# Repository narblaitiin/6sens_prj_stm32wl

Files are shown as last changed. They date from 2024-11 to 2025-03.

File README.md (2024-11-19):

# 6Sens: inSitu Seismic System for Slope Stability Sensing

## Desciption
The goal is to develop a warning system on the analysis of the evolution of the micro-seismic activity generated before the instability is triggered. The method uses a multitude of low-cost seismic sensors deployed in-situ in a network over the possibly unstable zone. The goal is to characterize the temporal evolution of seismic signals detected simultaneously by several sensors (i .e., co-detection). This method uses to its advantage the heterogeneity of the materials and the attenuation of the waves during their propagation in the material.

The design of these sensors is subject to certain technical constraints essential to good
operation of the project:

    - Be autonomous in energy, over a period of several months (so as not to have to return to site, often dangerous).
    - Be robust, reliable and adapted to extreme climatic conditions (cold, hot, humidity).
    - All sensors in the network must be synchronized precisely enough to perform the analysis (about 1/10 second).
    - Be able to communicate information in real time – or near – measurements to a gateway that will retransmit the data to a dedicated website.
    - Be produced at low cost (to install a large-scale network, and have the possibility of to install sensors in hazardous areas with the possibility of losing them).

## Hardware description
### Geophone sensor
The choice fell on omni geometric sensors from Geospace Technologies such Omni-X-LT or GS-ONE. Seismic geophone is a type of sensor that converts ground movement or a kind vibration into voltage, which could be acquired by an acquisition system. The deviation of this mesured voltage from the base line is called the geophone response and is analysed and for monitoring vibration generated by nature in our case.

The frequency response of the geophone is a kind of harmonic oscillator, which is deternined by corner frequency, around 15Hz for the chosen sensors and damping (typically 0.7 for our case).
Our application require the full wave to be sued and the three-component 3C geophones is used (Omni-X-LT or GS-ONE).
For more information, please to refer to : https://www.geospace.com/products/sensors/

### Amplification/Filtering board
The specifications inform us about the bandwidth of the filtering to be carried out: from 20Hz at 100Hz. So we have to build a band-pass filter having an amplification almost constant on this band and rejects frequencies outside this band. Moreover, the signal will have to be amplified in order to obtain a complete dynamic range between 0 and 3.3V without saturation. Below are listed the
parameters of the different filters that will make up the amplification and filtering card :

    - Filter 1 : active bandpass filter, gain : 33dB, low frequency : 7Hz, high frequency : 154Hz
    - Filter 2 : passive low-pass filter, no gain, cut frequency : 106Hz
    - Filter 3 : active low-pass filter, gain : 6dB, cut frequency : 234Hz

### CPU/Radio board for test
The choice fell on Cicerone MKR main board. Move-X Cicerone LoRa/GNSS Board is a high-performance, low-power, Arduino MKR-compatible development board based on the MAMWLE LoRa Module and the u-blox MAX-M10S GNSS Module. The Cicerone Board delivers best-in-class GNSS, long-range wireless connection, and high-performance MCU processing in a low-power solution for optimal battery life. The Cicerone Board allows users to build tracking applications worldwide with meter-level accuracy and to communicate long-range, low-power data via LoRaWAN. The integrated Li-Po charging circuit enables the Cicerone Board to manage battery charging through the USB port.

### CPU/Radio board for POC
The choice was made to manufacture our own PCB. It has three parts: the MAMWLE-01 radio chipset to transmit LoRaWAN packets (based on an STM32WLE5jx), a UWB chipset DW1000 to measure distance between two sensors and an analog part to supply radio chipset (solar panel or/and Li-Po battery). Connectors (Arduino MKR-compatible) have also been added to insert the seismic sensor amplification/filtering board.

## Firmware description
For this project, the use of Zephyr RTOS has been retained. To see what is Zephyr RTOS and how to install it on your computer, go to https://docs.zephyrproject.org/latest/develop/getting_started/index.html (it supports Linux OS, Windows OS and macOS).

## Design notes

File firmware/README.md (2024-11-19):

# Code for 6Sens Project : final code

## Overview
Here is the final code for the 6Sens (6Sens: inSitu Seismic System for Slope Stability Sensing) project. It makes it possible to measure seismic measurements and alert in the event of an alert. The data is stored in memory when an event appears and, when it stops, all samples are sent to the Lorawan networks servers then to a 5G network. All servers are implemeted in a Raspberry Pi3 model B and this gateway is powered by solar panel. In addition, the battery level and temperature/pressure/humidity of the node are taken every 30 minutes and sent to the network once a day.

## Building and Running
The following commands clean build folder, build and flash the sample:

**Command to use**

west build -t pristine

west build -p always -b stm32wl_dw1000_iot_board applications/stm32wle5_rtos_6sens

west flash --runner stm32cubeprogrammer

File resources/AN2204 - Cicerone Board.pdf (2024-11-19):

AN2204

# Application note

Hardware Specifications of Move-X Cicerone board

# Introduction

The purpose of this document is to guide users of Move-X Cicerone board in understanding and customizing the board’s hardware. To do this, the document provides electrical schematics that show how components are connected, and what kind of modifications can be done to adapt the board to different use cases.

For more resources, news, and links to official distributors for Move-X products, please visit Move-X website: https://www.move-x.it/.

For details on the Cicerone boards, documentation and buying options please visit the official website: https://www.move-x.it/cicerone-board/.

pag.

# Contents

Introduction

0
Contents

1
Electrical schematics

2
Connectors

2
USB

-UART interface chip

2
u

-blox MAX

-M10S module

3
Move

-X MAMWLE module

3
Auxiliary circuits

4
Hardware configuration

5
Document revision

6

# Electrical schematics

## Connectors

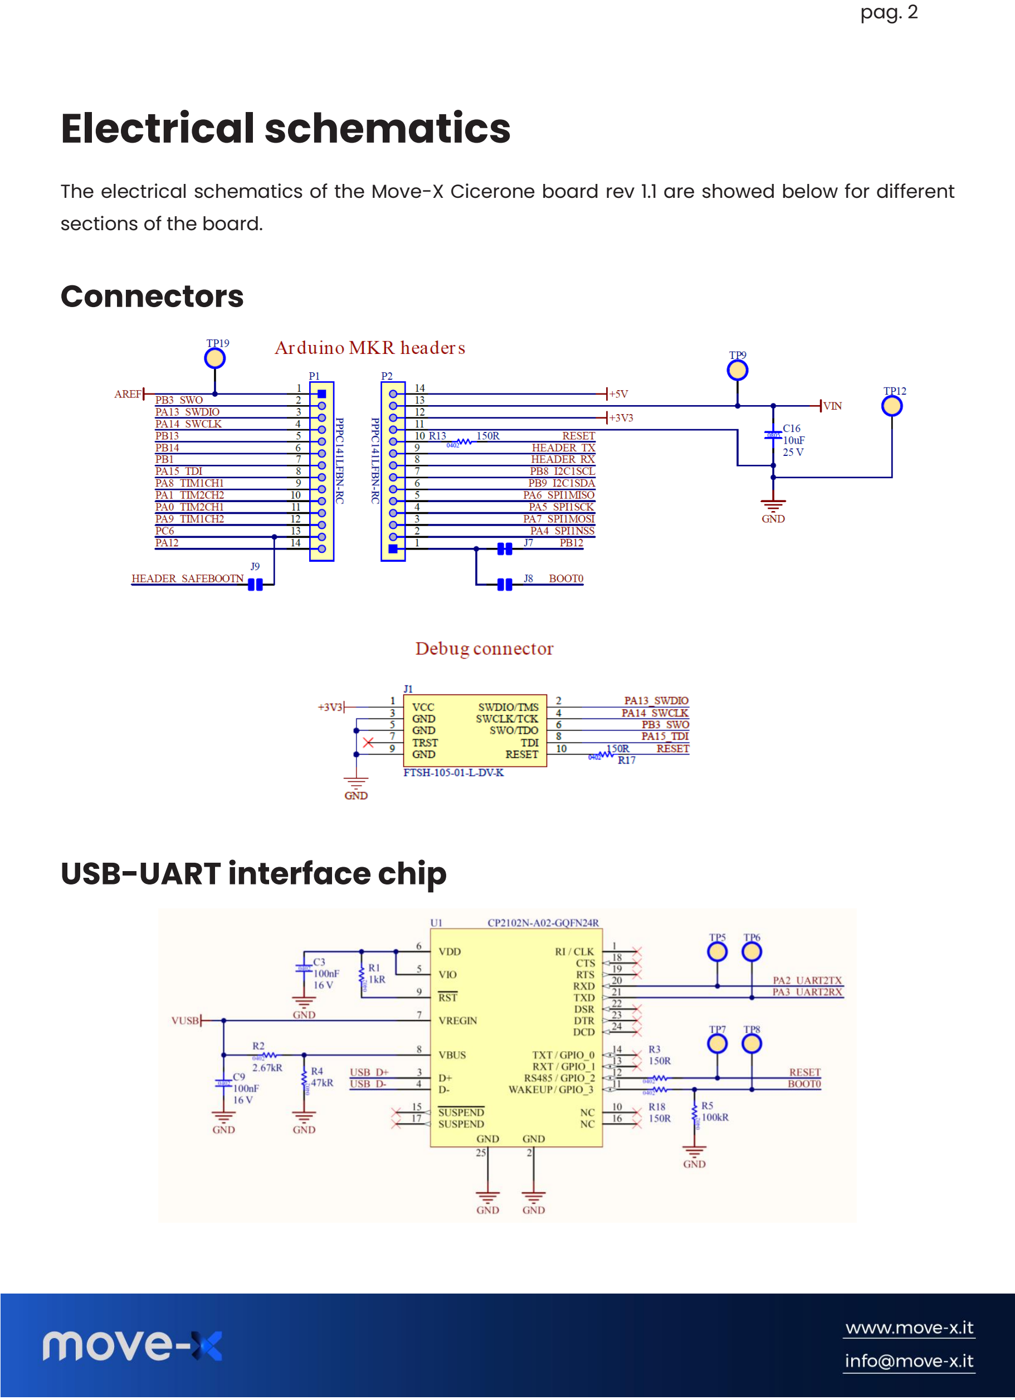
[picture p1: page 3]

The electrical schematics of the Move-X Cicerone board rev 1.1 are showed below for different sections of the board.

## USB-UART interface chip

## u-blox MAX-M10S module

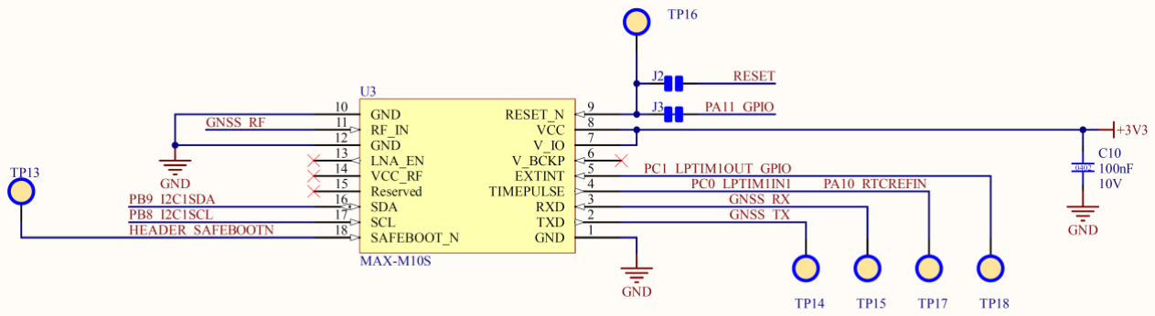
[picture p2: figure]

## Move-X MAMWLE module

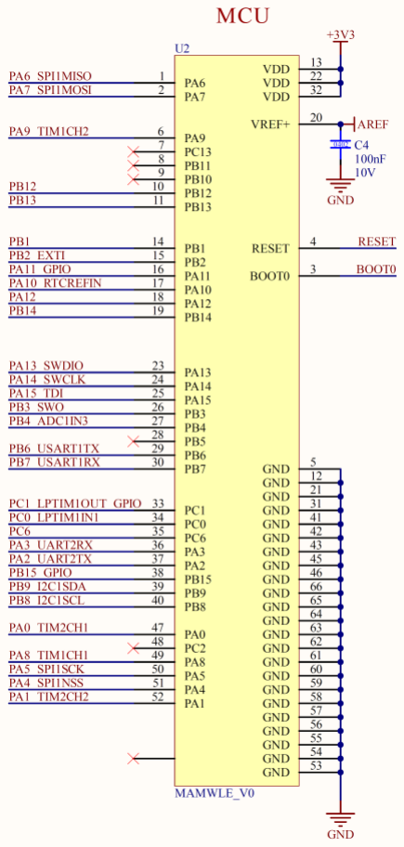
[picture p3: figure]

## Auxiliary circuits

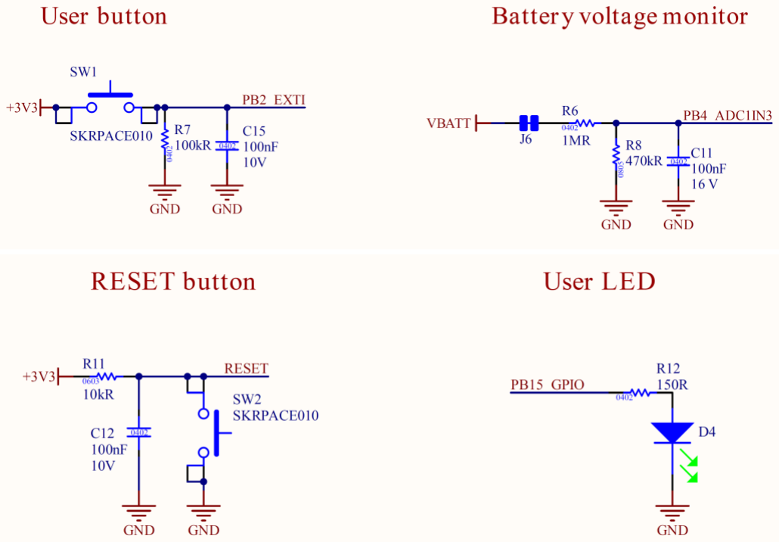
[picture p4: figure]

# Hardware configuration

The Cicerone board is equipped with some solder jumper on the bottom. These can be of two kinds as expressed in the schematics:
- Normally closed (NC): by default, the two terminals are shorted together, but can be separated by cutting the small track that connects the two pads.
- Normally open (NO): by default, the two terminals are not shorted together, but can be shorted by soldering them together.

The table below lists all the available solder jumpers with their respective function.

Designator | Default Type | Function description
J2 | NO | J2, J3 default state connects MAX-M10’s RESET_N pin to PA11. It is possible to close J2 and open J3 to connect MAX-M10’s RESET_N to the RESET net. J2 and J3 should not be both closed to avoid shorting RESET and PA11 nets.
J3 | NC
J6 | NC | Close by default for connecting the R6-R8 voltage divider to PB4, allowing battery voltage measurement using the ADC. Can be opened to disconnect this circuit from the battery.
J7 | NC | J7, J8 default state connects PB12 to the header pin #P2.1. It is possible to close J8 and open J7 to connect header pin #P2.1 to BOOT0 instead of PB12. J7 and J8 should not be both closed to avoid shorting BOOT0 and PB12 nets.
J8 | NO
J9 | NO | Open by default, can be closed to connect MAX-M10’s SAFEBOOT_N to header pin #P1.13 and PC6 net.
J10 | NC | Close by default, connects the battery charge IC to the battery. Can be open to disconnect the charging circuit from the battery. This allows to use non-rechargeable batteries.

## Document revision

Revision 1.0

- 23

/09/2022

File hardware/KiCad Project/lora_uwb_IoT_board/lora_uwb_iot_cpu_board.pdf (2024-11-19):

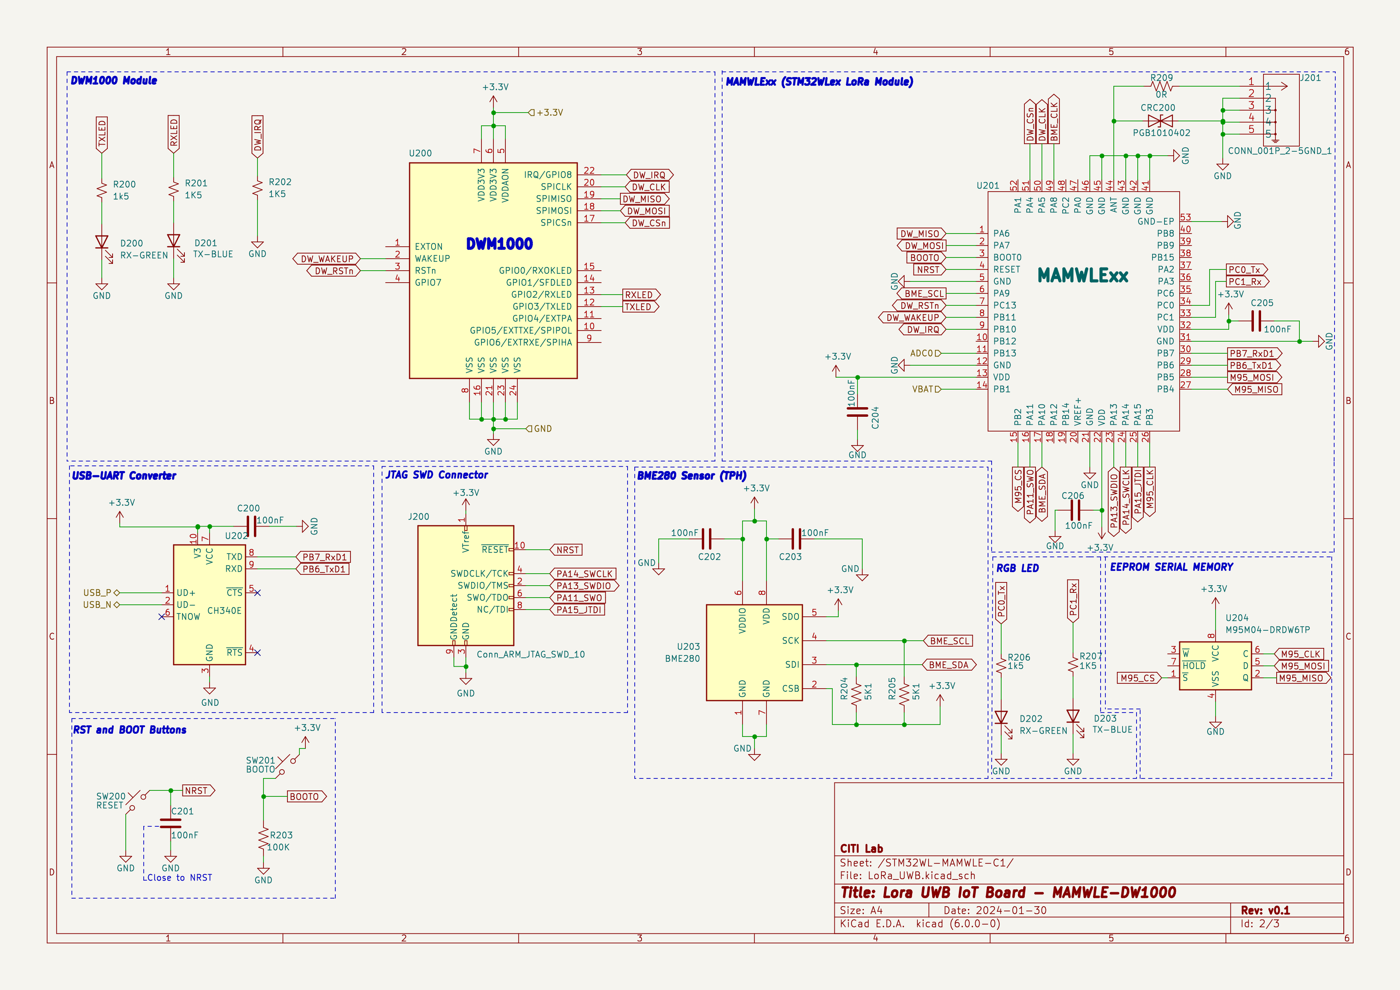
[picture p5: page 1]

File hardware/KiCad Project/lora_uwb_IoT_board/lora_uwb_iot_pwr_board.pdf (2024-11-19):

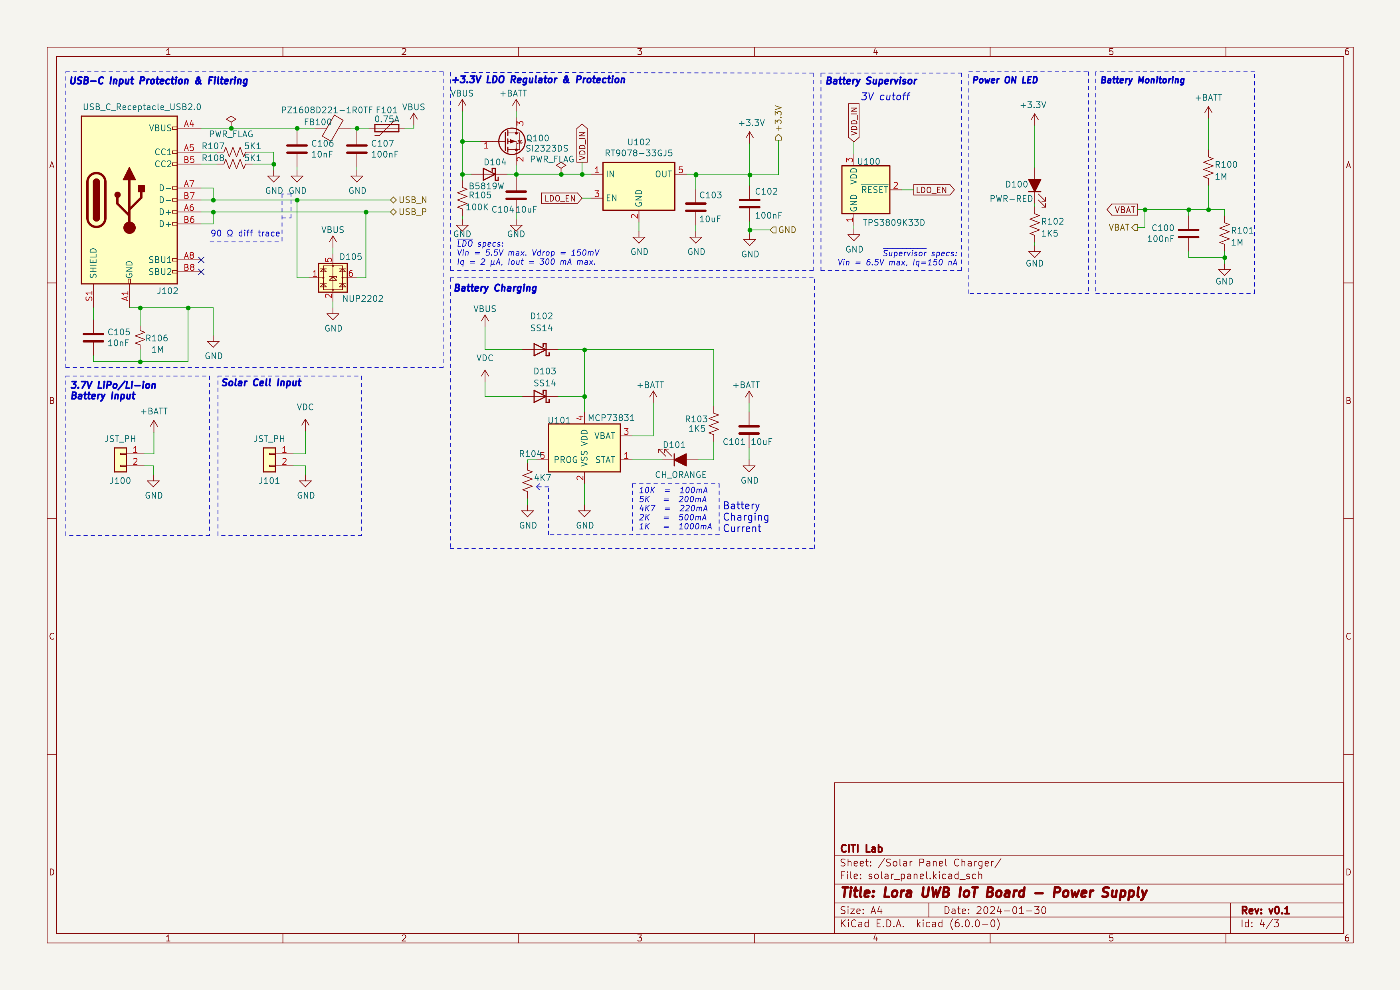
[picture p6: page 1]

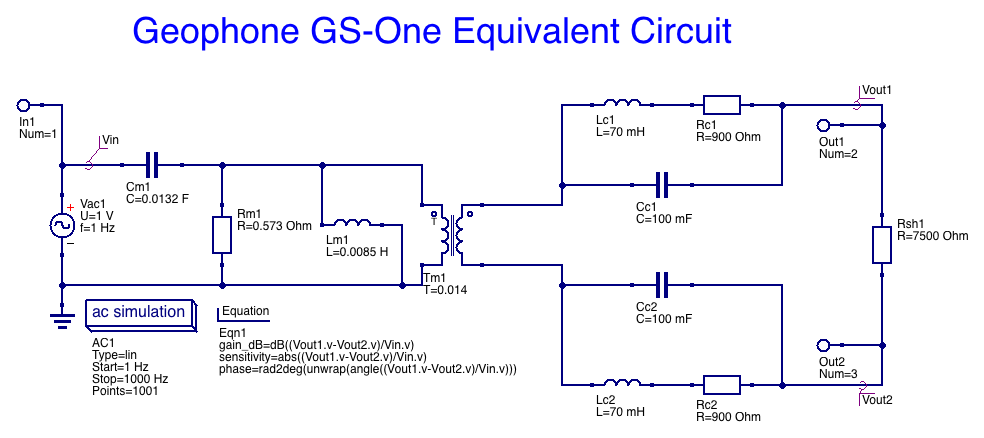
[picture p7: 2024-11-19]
hardware/Plots/geophone/sub_circuit.png

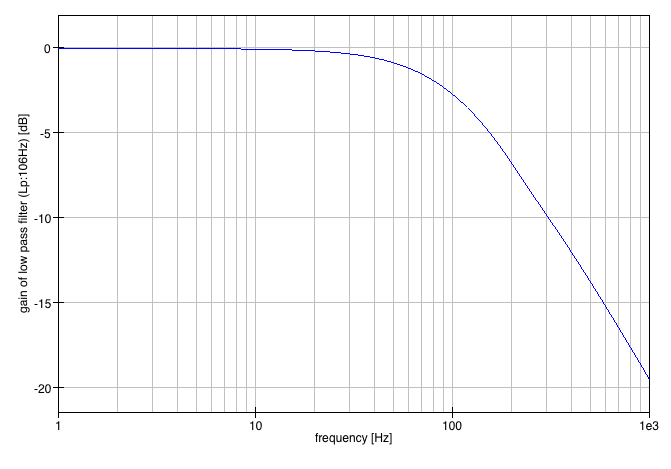
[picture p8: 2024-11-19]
hardware/Plots/amplifier/filter_2_output.png

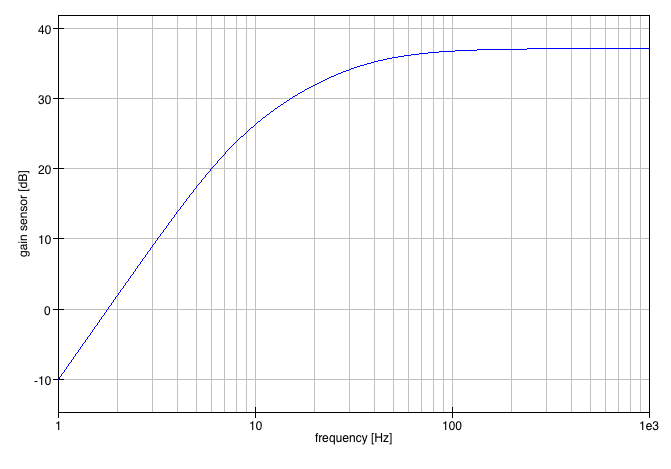
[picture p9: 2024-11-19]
hardware/Plots/amplifier/sensor_output.png

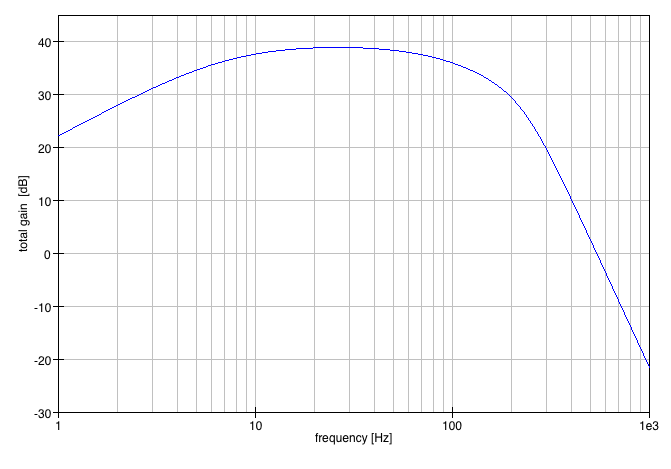
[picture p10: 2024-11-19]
hardware/Plots/amplifier/gain_tot.png

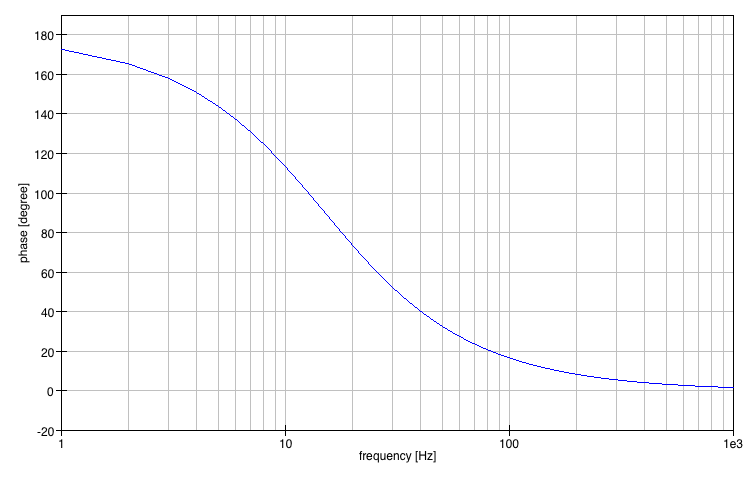
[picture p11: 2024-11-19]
hardware/Plots/geophone/phase.png

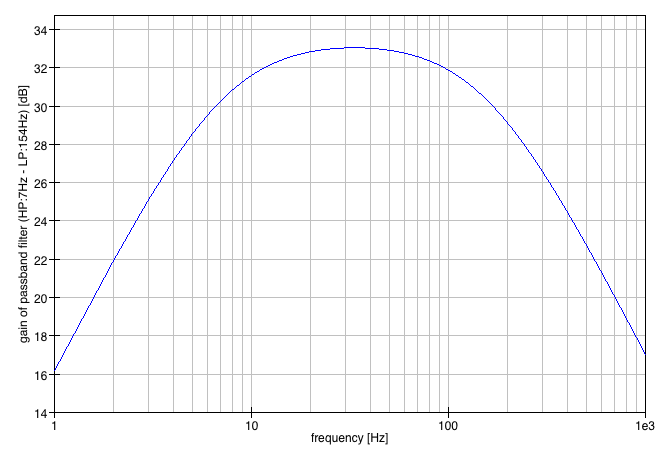
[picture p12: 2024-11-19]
hardware/Plots/amplifier/filter_1_output.png

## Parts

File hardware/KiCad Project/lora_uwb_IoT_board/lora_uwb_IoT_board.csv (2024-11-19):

Source: | /Users/gwongwen/Documents/KiCad/projects/lora_uwb_IoT_board/lora_uwb_IoT_board.kicad_sch
Date: | 2024 January 25, Thursday 10:08:41
Tool: | Eeschema (6.0.0-0)
Generator: | /private/var/folders/2p/244w4z5x3573cx4nmkc0qqpr0000gq/T/AppTranslocation/317323E5-9F59-4619-A53F-C4E1E08F8051/d/KiCad.app/Contents/SharedSupport/plugins/bom_csv_grouped_by_value.py
Component Count: | 67
Individual Components:
Item | Qty | Reference(s) | Value | LibPart | Footprint | Datasheet | LCSC_Part# | MPN | Manufacturer | Mfg
 |  | C100 | 100nF | Device:C | Capacitor_SMD:C_0402_1005Metric | ~ |  | GRM155R61A104KA01D | Murata Electronics
 |  | C101 | 10uF | Device:C | Capacitor_SMD:C_0603_1608Metric | ~ |  | GRT188C81A106ME13J | Murata Electronics
 |  | C102 | 100nF | Device:C | Capacitor_SMD:C_0402_1005Metric | ~ |  | GRM155R61A104KA01D | Murata Electronics
 |  | C103 | 10uF | Device:C | Capacitor_SMD:C_0603_1608Metric | ~ |  | GRT188C81A106ME13J | Murata Electronics | -
 |  | C104 | 10uF | Device:C | Capacitor_SMD:C_0603_1608Metric | ~ |  | GRT188C81A106ME13J | Murata Electronics | -
 |  | C105 | 10nF | Device:C | Capacitor_SMD:C_0402_1005Metric | ~ |  | GRM155R61A103KA01D | Murata Electronics
 |  | C106 | 10nF | Device:C | Capacitor_SMD:C_0402_1005Metric | ~ | Murata Electronics | GRM155R61A103KA01D
 |  | C107 | 100nF | Device:C | Capacitor_SMD:C_0402_1005Metric | ~ |  | GRM155R61A104KA01D | Murata Electronics
 |  | C200 | 100nF | Device:C | Capacitor_SMD:C_0402_1005Metric | ~ |  | GRM155R61A104KA01D | Murata Electronics
 |  | C201 | 100nF | Device:C | Capacitor_SMD:C_0402_1005Metric | ~ |  | GRM155R61A104KA01D | Murata Electronics
 |  | C202 | 100nF | Device:C | Capacitor_SMD:C_0402_1005Metric | ~ |  | GRM155R61A104KA01D | Murata Electronics
 |  | C203 | 100nF | Device:C | Capacitor_SMD:C_0402_1005Metric | ~ |  | GRM155R61A104KA01D | Murata Electronics
 |  | C204 | 100nF | Device:C | Capacitor_SMD:C_0402_1005Metric | ~ |  | GRM155R61A104KA01D | Murata Electronics
 |  | C205 | 100nF | Device:C | Capacitor_SMD:C_0402_1005Metric | ~ |  | GRM155R61A104KA01D | Murata Electronics
 |  | C206 | 100nF | Device:C | Capacitor_SMD:C_0402_1005Metric | ~ |  | GRM155R61A104KA01D | Murata Electronics
 |  | CRC200 | PGB1010402 | Diode:ESD9B5.0ST5G | pgb1010402:PGB1010402KR | https://www.onsemi.com/pub/Collateral/ESD9B-D.PDF |  | PGB1010402KR | Littelfues Inc
 |  | D100 | PWR-RED | Device:LED_ALT | LED_SMD:LED_0603_1608Metric |  |  | LTST-C191KRKT | Lite-On Inc | -
 |  | D101 | CH_ORANGE | Device:LED_ALT | LED_SMD:LED_0603_1608Metric |  |  | LTST-C191KFKT | Lite-On Inc | -
 |  | D102 | SS14 | Device:D_Schottky | Diode_SMD:D_SMA | ~ |  | SS14 | Onsemi
 |  | D103 | SS14 | Device:D_Schottky | Diode_SMD:D_SMA | ~ |  | SS14 | Onsemi
 |  | D104 | B5819W | Diode:MBR0520 | Diode_SMD:D_SOD-123 | http://www.mccsemi.com/up_pdf/MBR0520~MBR0580(SOD123).pdf |  | B5819W | Yangjie Electronic Technology
 |  | D105 | NUP2202 | Power_Protection:NUP2202 | Package_TO_SOT_SMD:SOT-363_SC-70-6 | http://www.onsemi.ru.com/pub_link/Collateral/NUP2202W1-D.PDF |  | NUP2202W1T2G | Onsemi
 |  | D200 | RX-GREEN | Device:LED | LED_SMD:LED_0603_1608Metric | ~ |  | LTST-C191KGKT | Lite-On Inc
 |  | D201 | TX-BLUE | Device:LED | LED_SMD:LED_0603_1608Metric | ~ |  | LTST-C191TBKT | Lite-On Inc
 |  | D202 | RX-GREEN | Device:LED | LED_SMD:LED_0603_1608Metric | ~ |  | LTST-C191KGKT | Lite-On Inc
 |  | D203 | TX-BLUE | Device:LED | LED_SMD:LED_0603_1608Metric | ~ |  | LTST-C191TBKT | Lite-On Inc
 |  | F101 | 0.75A | Device:Polyfuse | Fuse:Fuse_0805_2012Metric | ~ |  | SMD0805B075TF | Yageo
 |  | FB100 | PZ1608D221-1R0TF | Device:Ferrite_Bead | Inductor_SMD:L_0603_1608Metric |  |  | HPZ1608D221-1R2TF | Shenzhen Sunlord Electronics
 |  | J100 | JST_PH | Connector_Generic:Conn_01x02 | Connector_JST:JST_PH_S2B-PH-SM4-TB_1x02-1MP_P2.00mm_Horizontal | ~ |  | S2B-PH-SM4-TB(LF)(SN) | JST Sales America Inc
 |  | J101 | JST_PH | Connector_Generic:Conn_01x02 | Connector_JST:JST_PH_S2B-PH-SM4-TB_1x02-1MP_P2.00mm_Horizontal | ~ |  | S2B-PH-SM4-TB(LF)(SN) | JST Sales America Inc
 |  | J102 | USB_C_Receptacle_USB2.0 | Penguino-STM32WL-M-rescue:USB_C_Receptacle_USB2.0-Connector | Connector_USB:USB_C_Receptacle_Amphenol_12401548E4-2A | https://www.usb.org/sites/default/files/documents/usb_type-c.zip |  | 12401598E4#2A | Amphenol ICC
 |  | J200 | Conn_ARM_JTAG_SWD_10 | Connector:Conn_ARM_JTAG_SWD_10 | Connector_PinHeader_1.27mm:PinHeader_2x05_P1.27mm_Vertical_SMD | http://infocenter.arm.com/help/topic/com.arm.doc.ddi0314h/DDI0314H_coresight_components_trm.pdf |  | 20021121-00010C4LF | Amphenol ICC
 |  | J201 | CONN_001P_2-5GND_1 | sma-142-0701-851:CONN_001P_2-5GND_1 | sma-142-0701-851:142-0701-851 |  |  | 142-0701-851 | Cinch Connectivity
 |  | MK1 | Mounting_Hole_PAD | EuroCard160mmX100mm_holes:Mounting_Hole_PAD-Mechanical | Mounting_Holes:MountingHole_2.7mm
 |  | MK2 | Mounting_Hole_PAD | EuroCard160mmX100mm_holes:Mounting_Hole_PAD-Mechanical | Mounting_Holes:MountingHole_2.7mm
 |  | MK3 | Mounting_Hole_PAD | EuroCard160mmX100mm_holes:Mounting_Hole_PAD-Mechanical | Mounting_Holes:MountingHole_2.7mm
 |  | MK4 | Mounting_Hole_PAD | EuroCard160mmX100mm_holes:Mounting_Hole_PAD-Mechanical | Mounting_Holes:MountingHole_2.7mm
 |  | Q100 | SI2323DS | Device:Q_PMOS_GSD | Package_TO_SOT_SMD:SOT-23 | ~ |  | SI2323DS-T1-GE3 | Vishay Siliconix
 |  | R100 | 1M | Device:R_US | Resistor_SMD:R_0402_1005Metric | ~ |  | RC0402JR-071ML | Yageo
 |  | R101 | 1M | Device:R_US | Resistor_SMD:R_0402_1005Metric | ~ |  | RC0402JR-071ML | Yageo
 |  | R102 | 1K5 | Device:R_US | Resistor_SMD:R_0402_1005Metric | ~ |  | RC0402JR-071K5L | Yageo
 |  | R103 | 1K5 | Device:R_US | Resistor_SMD:R_0402_1005Metric | ~ |  | RC0402JR-071K5L | Yageo
 |  | R104 | 4K7 | Device:R_US | Resistor_SMD:R_0402_1005Metric | ~ |  | RC0402JR-074K7L | Yageo
 |  | R105 | 100K | Device:R_US | Resistor_SMD:R_0402_1005Metric | ~ |  | RC0402JR-07100KL | Yageo
 |  | R106 | 1M | Device:R_Small_US | Resistor_SMD:R_0402_1005Metric | ~ |  | RC0402JR-071ML | Yageo | -
 |  | R107 | 5K1 | Device:R_US | Resistor_SMD:R_0402_1005Metric | ~ |  | RC0402FR-075K1L | Yageo
 |  | R108 | 5K1 | Device:R_US | Resistor_SMD:R_0402_1005Metric | ~ |  | RC0402FR-075K1L | Yageo
 |  | R200 | 1k5 | Device:R_Small_US | Resistor_SMD:R_0402_1005Metric | ~ |  | RC0402JR-071K5L | Yageo
 |  | R201 | 1K5 | Device:R_Small_US | Resistor_SMD:R_0402_1005Metric | ~ |  | RC0402JR-071K5L | Yageo
 |  | R202 | 1K5 | Device:R_Small_US | Resistor_SMD:R_0402_1005Metric | ~ |  | RC0402JR-071K5L | Yageo
 |  | R203 | 100K | Device:R_US | Resistor_SMD:R_0402_1005Metric | ~ |  | RC0402JR-07100KL | Yageo
 |  | R204 | 5K1 | Device:R_US | Resistor_SMD:R_0402_1005Metric | ~ |  | RC0402FR-075K1L | Yageo
 |  | R205 | 5K1 | Device:R_US | Resistor_SMD:R_0402_1005Metric | ~ |  | RC0402FR-075K1L | Yageo
 |  | R206 | 1k5 | Device:R_Small_US | Resistor_SMD:R_0402_1005Metric | ~ |  | RC0402JR-071K5L | Yageo
 |  | R207 | 1K5 | Device:R_Small_US | Resistor_SMD:R_0402_1005Metric | ~ |  | RC0402JR-071K5L | Yageo
 |  | R209 | 0R | Device:R_US | Resistor_SMD:R_0402_1005Metric | ~ |  | RC0402JR-070RL | Yageo
 |  | SW200 | RESET | Switch:SW_Push_45deg | Button_Switch_SMD:SW_Push_1P1T_NO_Vertical_Wuerth_434133025816 | ~ |  | 434133025816 | Wurth Elektronik
 |  | SW201 | BOOTO | Switch:SW_Push_45deg | Button_Switch_SMD:SW_Push_1P1T_NO_Vertical_Wuerth_434133025816 | ~ |  | 434133025816 | Wurth Elektronik
 |  | U100 | TPS3809K33D | Power_Supervisor:TPS3839DBZ | Package_TO_SOT_SMD:SOT-23 | http://www.ti.com/lit/ds/sbvs193d/sbvs193d.pdf |  | TPS3809K33DBVRG4 | Texas Instrument
 |  | U101 | MCP73831 | Battery_Management:MCP73831-2-OT | Package_TO_SOT_SMD:SOT-23-5 | http://ww1.microchip.com/downloads/en/DeviceDoc/20001984g.pdf |  | MCP73831T-2ACI/OT | Microchip Technology
 |  | U102 | RT9078-33GJ5 | Regulator_Linear:NCV8114ASN120T1G | Package_TO_SOT_SMD:TSOT-23-5 | https://ru.mouser.com/datasheet/2/308/NCV8114-D-1107616.pdf |  | RT9078-33GJ5 | Richtek USA Inc
 |  | U200 | DWM1000 | RF_Module:DWM1000 | RF_Module:DWM1000 | https://www.decawave.com/sites/default/files/resources/dwm1000-datasheet-v1.3.pdf |  | DWM1000 | Qorvo
 |  | U201 | MAMWLExx | stm32wl-lib-v1:MAMWLExx | MAMWLExx:MAMWLExx |  |  | MAMWLE-01 | Move-X
 |  | U202 | CH340E | Interface_USB:CH340E | Package_SO:MSOP-10_3x3mm_P0.5mm | https://www.mpja.com/download/35227cpdata.pdf |  | COM-16278 | Sparkfun Electronics
 |  | U203 | BME280 | Sensor:BME280 | Package_LGA:Bosch_LGA-8_2.5x2.5mm_P0.65mm_ClockwisePinNumbering | https://ae-bst.resource.bosch.com/media/_tech/media/datasheets/BST-BME280-DS002.pdf |  | 828-1063-2-ND | Bosch Sensortec
 |  | U204 | M95M04-DRDW6TP | Memory_EEPROM:M95256-WMN6P | Package_SO:TSSOP-8_4.4x3mm_P0.65mm | http://www.st.com/content/ccc/resource/technical/document/datasheet/9d/75/f0/3e/76/00/4c/0b/CD00103810.pdf/files/CD00103810.pdf/jcr:content/translations/en.CD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
 |  | U300 | Feather-Generic | Penguino-STM32WL-M-rescue:Feather-Generic-my-Arduino-Boards-TLM-4260-breakout-v1_0-rescue-TinyLoRa-4260-breakout-v1_0-rescue-TinyLoRa-Feather-4260-v1_0-rescue-Penguino-Feather-4260-v1_0-rescue-Penguino-Feather-4260-v1_0-rescue-Penguino-Feather-4260-v1-rescue-Penguino-STM32WL-rescue-Penguino-STM32WL-MAMWLE-rescue | penguino_v1:Feather-Generic-no-holes
Collated Components:
Item | Qty | Reference(s) | Value | LibPart | Footprint | Datasheet | LCSC_Part# | MPN | Manufacturer | Mfg
1 | 10 | C100, C102, C107, C200, C201, C202, C203, C204, C205, C206 | 100nF | Device:C | Capacitor_SMD:C_0402_1005Metric | ~ |  | GRM155R61A104KA01D | Murata Electronics
2 | 3 | C101, C103, C104 | 10uF | Device:C | Capacitor_SMD:C_0603_1608Metric | ~ |  | GRT188C81A106ME13J | Murata Electronics | -
3 | 2 | C105, C106 | 10nF | Device:C | Capacitor_SMD:C_0402_1005Metric | ~ | Murata Electronics | GRM155R61A103KA01D | Murata Electronics
4 | 1 | CRC200 | PGB1010402 | Diode:ESD9B5.0ST5G | pgb1010402:PGB1010402KR | https://www.onsemi.com/pub/Collateral/ESD9B-D.PDF |  | PGB1010402KR | Littelfues Inc
5 | 1 | D100 | PWR-RED | Device:LED_ALT | LED_SMD:LED_0603_1608Metric |  |  | LTST-C191KRKT | Lite-On Inc | -
6 | 1 | D101 | CH_ORANGE | Device:LED_ALT | LED_SMD:LED_0603_1608Metric |  |  | LTST-C191KFKT | Lite-On Inc | -
7 | 2 | D102, D103 | SS14 | Device:D_Schottky | Diode_SMD:D_SMA | ~ |  | SS14 | Onsemi
8 | 1 | D104 | B5819W | Diode:MBR0520 | Diode_SMD:D_SOD-123 | http://www.mccsemi.com/up_pdf/MBR0520~MBR0580(SOD123).pdf |  | B5819W | Yangjie Electronic Technology
9 | 1 | D105 | NUP2202 | Power_Protection:NUP2202 | Package_TO_SOT_SMD:SOT-363_SC-70-6 | http://www.onsemi.ru.com/pub_link/Collateral/NUP2202W1-D.PDF |  | NUP2202W1T2G | Onsemi
10 | 2 | D200, D202 | RX-GREEN | Device:LED | LED_SMD:LED_0603_1608Metric | ~ |  | LTST-C191KGKT | Lite-On Inc
11 | 2 | D201, D203 | TX-BLUE | Device:LED | LED_SMD:LED_0603_1608Metric | ~ |  | LTST-C191TBKT | Lite-On Inc
12 | 1 | F101 | 0.75A | Device:Polyfuse | Fuse:Fuse_0805_2012Metric | ~ |  | SMD0805B075TF | Yageo
13 | 1 | FB100 | PZ1608D221-1R0TF | Device:Ferrite_Bead | Inductor_SMD:L_0603_1608Metric |  |  | HPZ1608D221-1R2TF | Shenzhen Sunlord Electronics
14 | 2 | J100, J101 | JST_PH | Connector_Generic:Conn_01x02 | Connector_JST:JST_PH_S2B-PH-SM4-TB_1x02-1MP_P2.00mm_Horizontal | ~ |  | S2B-PH-SM4-TB(LF)(SN) | JST Sales America Inc
15 | 1 | J102 | USB_C_Receptacle_USB2.0 | Penguino-STM32WL-M-rescue:USB_C_Receptacle_USB2.0-Connector | Connector_USB:USB_C_Receptacle_Amphenol_12401548E4-2A | https://www.usb.org/sites/default/files/documents/usb_type-c.zip |  | 12401598E4#2A | Amphenol ICC
16 | 1 | J200 | Conn_ARM_JTAG_SWD_10 | Connector:Conn_ARM_JTAG_SWD_10 | Connector_PinHeader_1.27mm:PinHeader_2x05_P1.27mm_Vertical_SMD | http://infocenter.arm.com/help/topic/com.arm.doc.ddi0314h/DDI0314H_coresight_components_trm.pdf |  | 20021121-00010C4LF | Amphenol ICC
17 | 1 | J201 | CONN_001P_2-5GND_1 | sma-142-0701-851:CONN_001P_2-5GND_1 | sma-142-0701-851:142-0701-851 |  |  | 142-0701-851 | Cinch Connectivity
18 | 4 | MK1, MK2, MK3, MK4 | Mounting_Hole_PAD | EuroCard160mmX100mm_holes:Mounting_Hole_PAD-Mechanical | Mounting_Holes:MountingHole_2.7mm
19 | 1 | Q100 | SI2323DS | Device:Q_PMOS_GSD | Package_TO_SOT_SMD:SOT-23 | ~ |  | SI2323DS-T1-GE3 | Vishay Siliconix
20 | 2 | R100, R101 | 1M | Device:R_US | Resistor_SMD:R_0402_1005Metric | ~ |  | RC0402JR-071ML | Yageo
21 | 2 | R102, R103 | 1K5 | Device:R_US | Resistor_SMD:R_0402_1005Metric | ~ |  | RC0402JR-071K5L | Yageo
22 | 1 | R104 | 4K7 | Device:R_US | Resistor_SMD:R_0402_1005Metric | ~ |  | RC0402JR-074K7L | Yageo
23 | 2 | R105, R203 | 100K | Device:R_US | Resistor_SMD:R_0402_1005Metric | ~ |  | RC0402JR-07100KL | Yageo
24 | 1 | R106 | 1M | Device:R_Small_US | Resistor_SMD:R_0402_1005Metric | ~ |  | RC0402JR-071ML | Yageo | -
25 | 4 | R107, R108, R204, R205 | 5K1 | Device:R_US | Resistor_SMD:R_0402_1005Metric | ~ |  | RC0402FR-075K1L | Yageo
26 | 2 | R200, R206 | 1k5 | Device:R_Small_US | Resistor_SMD:R_0402_1005Metric | ~ |  | RC0402JR-071K5L | Yageo
27 | 3 | R201, R202, R207 | 1K5 | Device:R_Small_US | Resistor_SMD:R_0402_1005Metric | ~ |  | RC0402JR-071K5L | Yageo
28 | 1 | R209 | 0R | Device:R_US | Resistor_SMD:R_0402_1005Metric | ~ |  | RC0402JR-070RL | Yageo
29 | 1 | SW200 | RESET | Switch:SW_Push_45deg | Button_Switch_SMD:SW_Push_1P1T_NO_Vertical_Wuerth_434133025816 | ~ |  | 434133025816 | Wurth Elektronik
30 | 1 | SW201 | BOOTO | Switch:SW_Push_45deg | Button_Switch_SMD:SW_Push_1P1T_NO_Vertical_Wuerth_434133025816 | ~ |  | 434133025816 | Wurth Elektronik
31 | 1 | U100 | TPS3809K33D | Power_Supervisor:TPS3839DBZ | Package_TO_SOT_SMD:SOT-23 | http://www.ti.com/lit/ds/sbvs193d/sbvs193d.pdf |  | TPS3809K33DBVRG4 | Texas Instrument
32 | 1 | U101 | MCP73831 | Battery_Management:MCP73831-2-OT | Package_TO_SOT_SMD:SOT-23-5 | http://ww1.microchip.com/downloads/en/DeviceDoc/20001984g.pdf |  | MCP73831T-2ACI/OT | Microchip Technology
33 | 1 | U102 | RT9078-33GJ5 | Regulator_Linear:NCV8114ASN120T1G | Package_TO_SOT_SMD:TSOT-23-5 | https://ru.mouser.com/datasheet/2/308/NCV8114-D-1107616.pdf |  | RT9078-33GJ5 | Richtek USA Inc
34 | 1 | U200 | DWM1000 | RF_Module:DWM1000 | RF_Module:DWM1000 | https://www.decawave.com/sites/default/files/resources/dwm1000-datasheet-v1.3.pdf |  | DWM1000 | Qorvo
35 | 1 | U201 | MAMWLExx | stm32wl-lib-v1:MAMWLExx | MAMWLExx:MAMWLExx |  |  | MAMWLE-01 | Move-X
36 | 1 | U202 | CH340E | Interface_USB:CH340E | Package_SO:MSOP-10_3x3mm_P0.5mm | https://www.mpja.com/download/35227cpdata.pdf |  | COM-16278 | Sparkfun Electronics
37 | 1 | U203 | BME280 | Sensor:BME280 | Package_LGA:Bosch_LGA-8_2.5x2.5mm_P0.65mm_ClockwisePinNumbering | https://ae-bst.resource.bosch.com/media/_tech/media/datasheets/BST-BME280-DS002.pdf |  | 828-1063-2-ND | Bosch Sensortec
38 | 1 | U204 | M95M04-DRDW6TP | Memory_EEPROM:M95256-WMN6P | Package_SO:TSSOP-8_4.4x3mm_P0.65mm | http://www.st.com/content/ccc/resource/technical/document/datasheet/9d/75/f0/3e/76/00/4c/0b/CD00103810.pdf/files/CD00103810.pdf/jcr:content/translations/en.CD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
39 | 1 | U300 | Feather-Generic | Penguino-STM32WL-M-rescue:Feather-Generic-my-Arduino-Boards-TLM-4260-breakout-v1_0-rescue-TinyLoRa-4260-breakout-v1_0-rescue-TinyLoRa-Feather-4260-v1_0-rescue-Penguino-Feather-4260-v1_0-rescue-Penguino-Feather-4260-v1_0-rescue-Penguino-Feather-4260-v1-rescue-Penguino-STM32WL-rescue-Penguino-STM32WL-MAMWLE-rescue | penguino_v1:Feather-Generic-no-holes

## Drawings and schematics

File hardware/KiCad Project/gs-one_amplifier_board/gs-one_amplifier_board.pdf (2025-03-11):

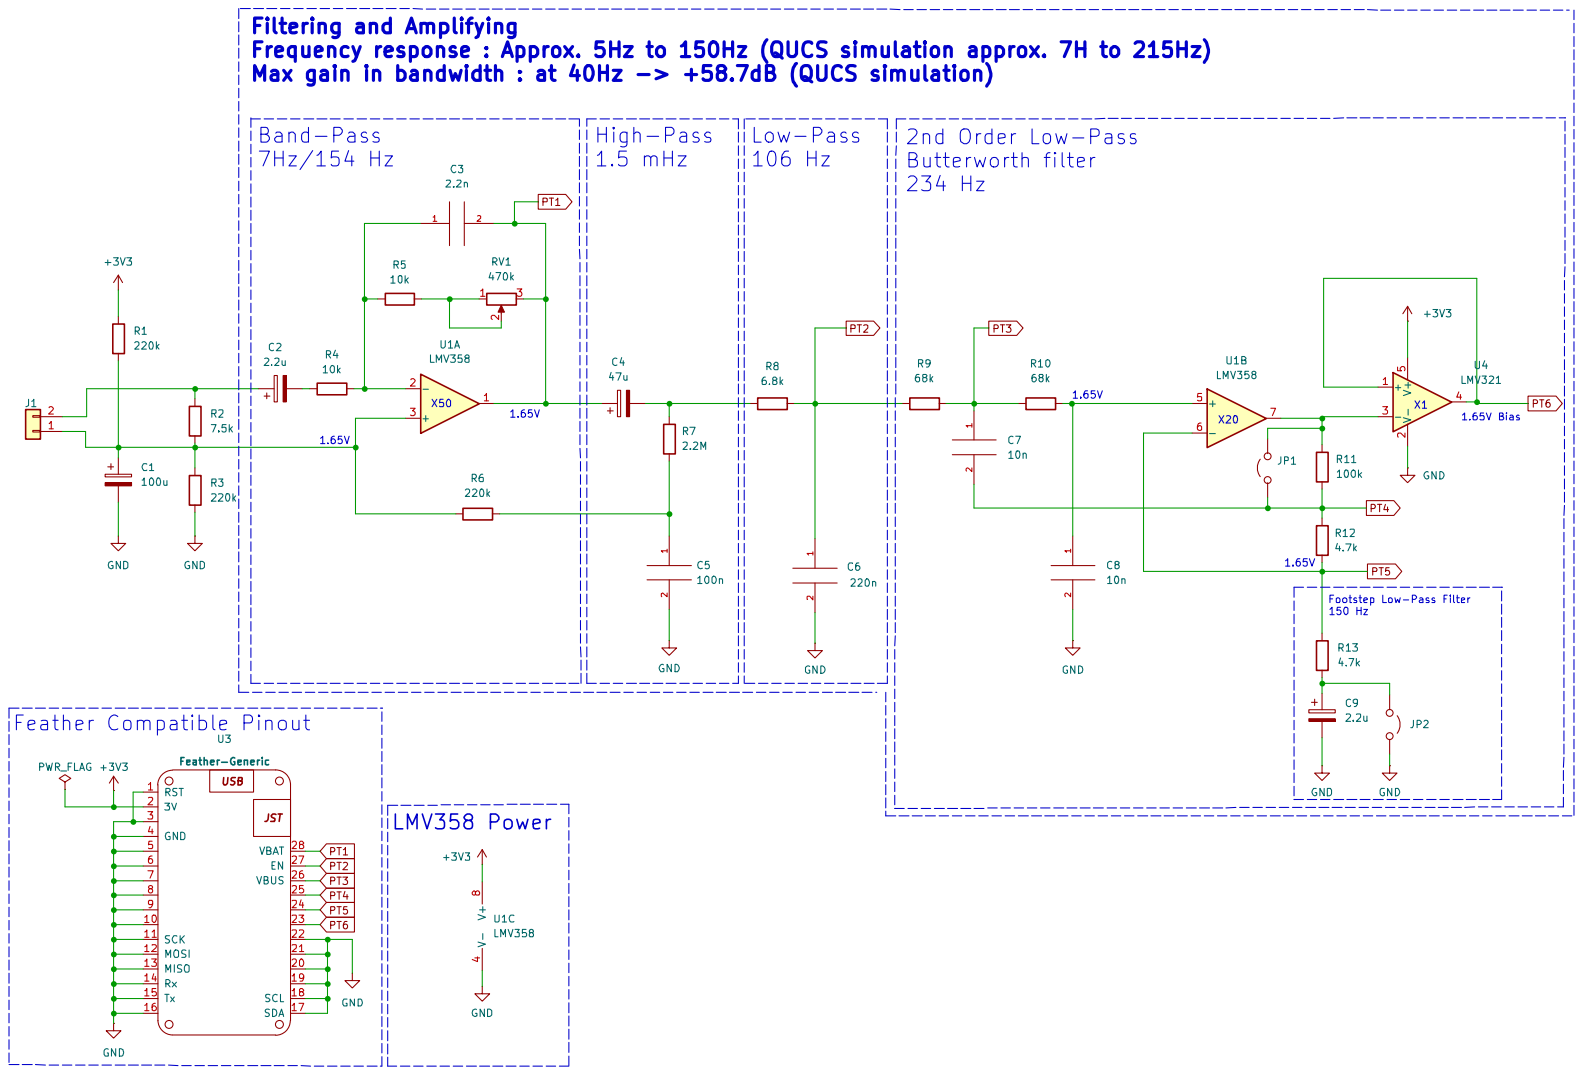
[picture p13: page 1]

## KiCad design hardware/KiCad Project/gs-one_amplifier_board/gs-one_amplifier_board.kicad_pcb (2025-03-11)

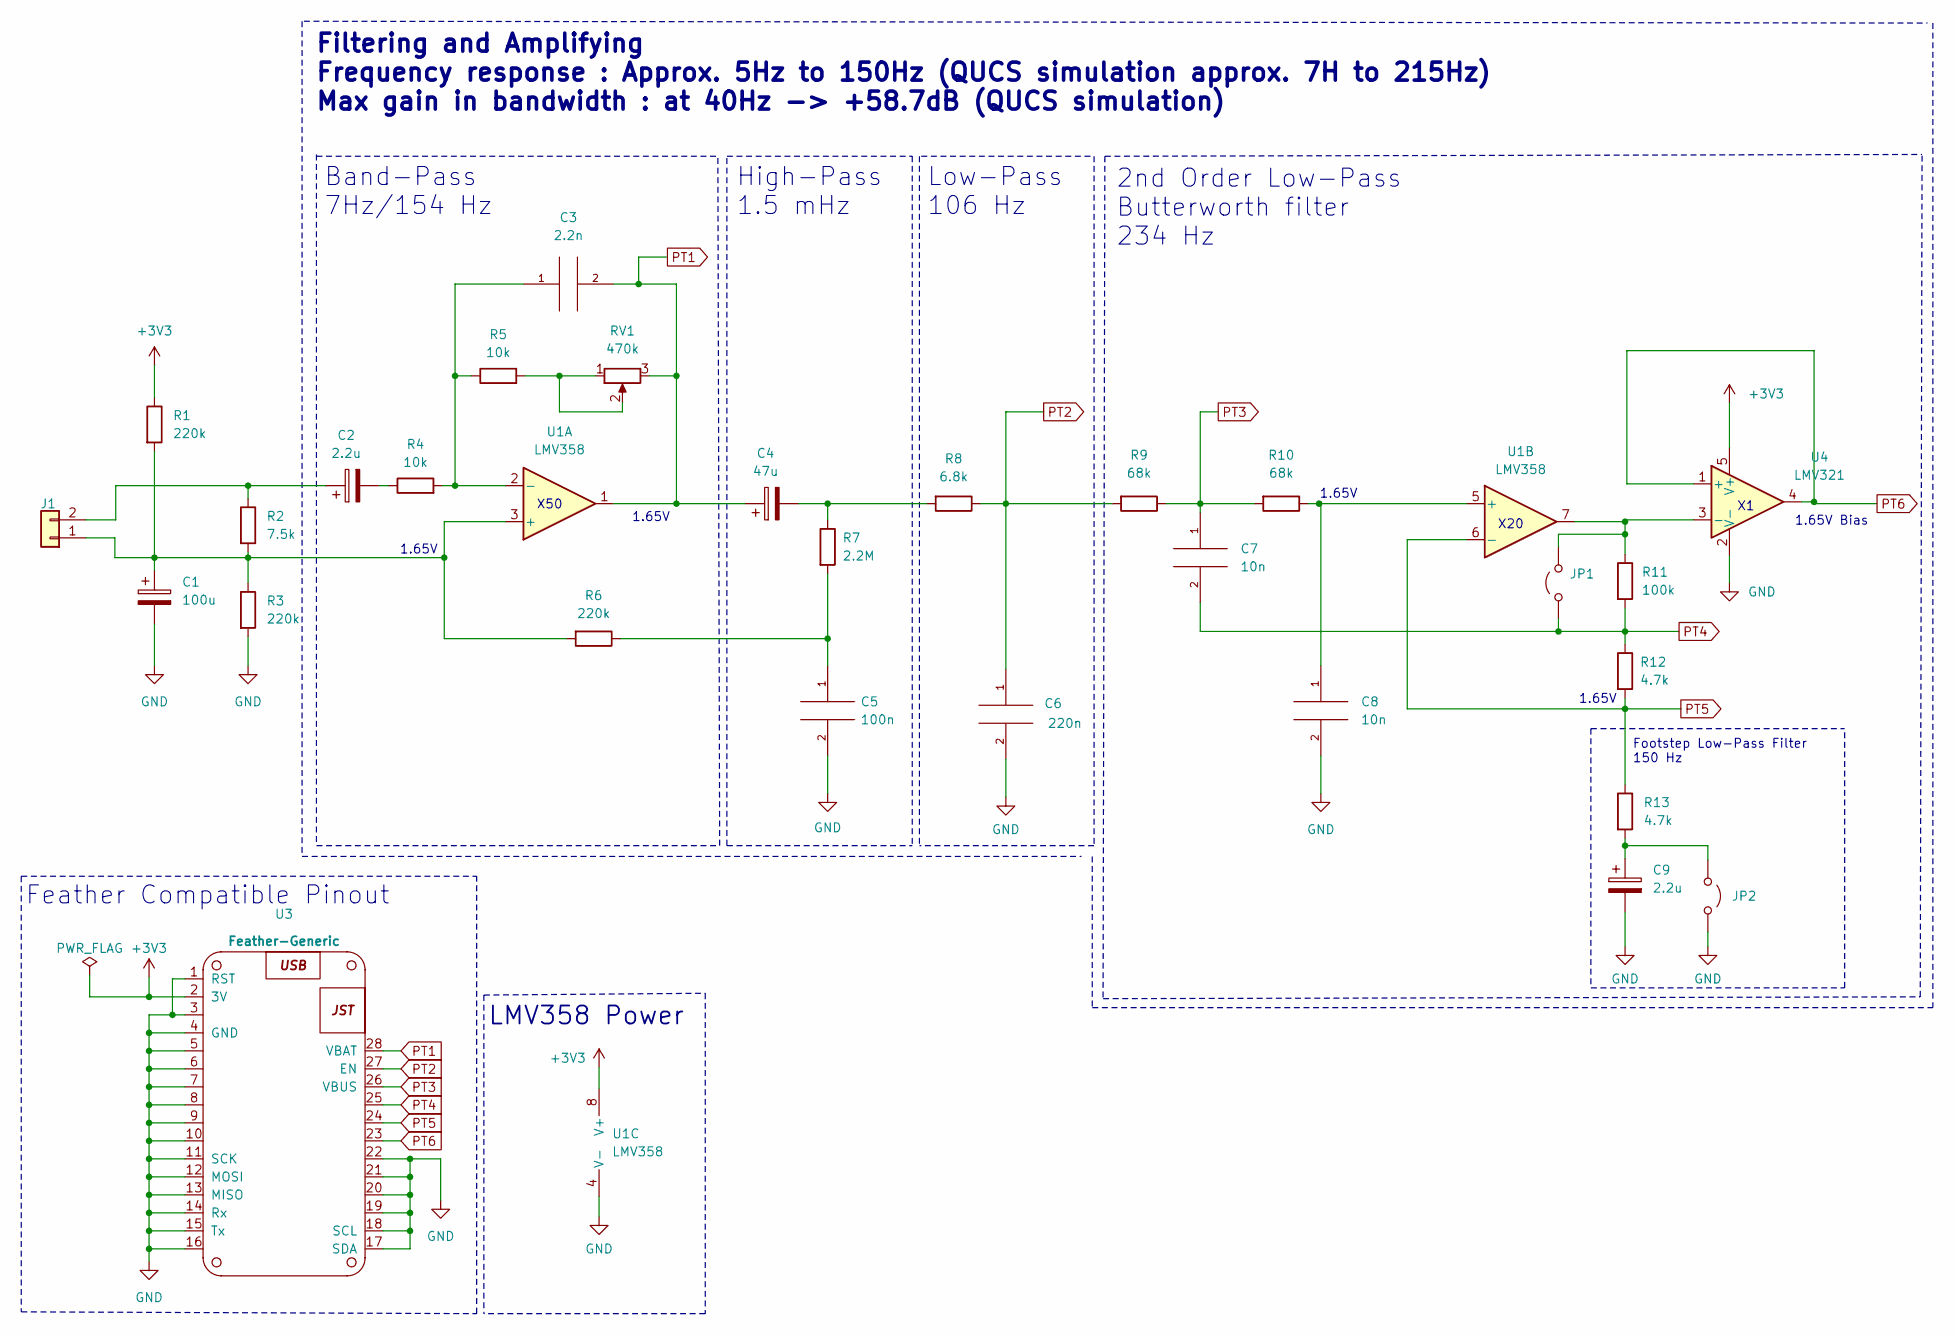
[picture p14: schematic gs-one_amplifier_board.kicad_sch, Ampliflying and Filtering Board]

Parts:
C1: 100u; C_1206_3216Metric; MPN GRM31CD80J107MEA8K
C2, C9: 2.2u; C_0603_1608Metric; MPN GRM188R61E106KA73J
C3: 2.2n; C_0603_1608Metric; MPN GRM1885C1H222FA01D
C4: 47u; C_0603_1608Metric; MPN GRM188R60J476ME01D
C5: 100n; C_0603_1608Metric; MPN GRM188R72A104KA35D
C6: 220n; C_0603_1608Metric; MPN GRM188R71E224KA88D
C7: 10n; C_0603_1608Metric; MPN GCM219R91H103KA37D
C8: 10n; C_0603_1608Metric; MPN GRM1885C1H103JA01D
J1: Conn_01x02; JST_PH_S2B-PH-SM4-TB_1x02-1MP_P2.00mm_Horizontal; MPN B2B-PH-SM4-TB(LF)(SN)
JP1, JP2: Jumper_2_Open; PinHeader_1x02_P1.27mm_Vertical
R1, R3, R6: 220k; R_0603_1608Metric; MPN RC0603FR-07220KL
R2: 7.5k; R_0603_1608Metric; MPN RC0603FR-077K5L
R4, R5: 10k; R_0603_1608Metric; MPN RC0603FR-0710KL
R7: 2.2M; R_0603_1608Metric; MPN RC0603FR-072M2L
R8: 6.8k; R_0603_1608Metric; MPN RC0603FR-076K8L
R9, R10: 68k; R_0603_1608Metric; MPN RC0603FR-076K8L
R11: 100k; R_0603_1608Metric; MPN RC0603FR-07100KL
R12, R13: 4.7k; R_0603_1608Metric; MPN RC0603FR-074K7L
RV1: 470k; Potentiometer_Bourns_3386P_Vertical; MPN 3386P-1-474LF
U1: LMV358; M08A-M; MPN LMV358IDR
U3: Feather-Generic; Feather-Generic-no-holes
U4: LMV321; DCK5

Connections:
+3V3: R1.1, U1.8 (V+), U3.2 (3V), U4.5 (V+)
GND: C1.2, C5.2, C6.2, C8.2, C9.2, JP2.1 (A), R3.2, U1.4 (V-), U3.1 (RST), U3.3, U3.4 (GND), U3.5, U3.6, U3.7, U3.8, U3.9, U3.10, U3.11 (SCK), U3.12 (MOSI), U3.13 (MISO), U3.14 (Rx), U3.15 (Tx), U3.16, U3.17 (SDA), U3.18 (SCL), U3.19, U3.20, U3.21, U3.22, U4.2 (V-)
unnamed: C2.2, R4.1
unnamed: C4.2, R7.1, R8.2
unnamed: C5.1, R6.1, R7.2
unnamed: C1.1, J1.1, R1.2, R2.2, R3.1, R6.2, U1.3 (+)
unnamed: C2.1, J1.2, R2.1
unnamed: JP1.2 (B), R11.1, U1.7, U4.3 (-)
unnamed: C9.1, JP2.2 (B), R13.2
unnamed: R5.2, RV1.1, RV1.2
unnamed: C3.1, R4.2, R5.1, U1.2 (-)
unnamed: C8.1, R10.1, U1.5 (+)
PT1: C3.2, C4.1, RV1.3, U1.1, U3.28 (VBAT)
PT2: C6.1, R8.1, R9.2, U3.27 (EN)
PT3: C7.1, R9.1, R10.2, U3.26 (VBUS)
PT4: C7.2, JP1.1 (A), R11.2, R12.1, U3.25
PT5: R12.2, R13.1, U1.6 (-), U3.24
PT6: U3.23, U4.1 (+), U4.4

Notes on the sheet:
1.65V
Filtering and Amplifying Frequency response : Approx. 5Hz to 150Hz (QUCS simulation approx. 7H to 215Hz) Max gain in bandwidth : at 40Hz -> +58.7dB (QUCS simulation)
1.65V Bias
Feather Compatible Pinout
Footstep Low-Pass Filter 150 Hz
High-Pass 1.5 mHz
Band-Pass 7Hz/154 Hz
Low-Pass 106 Hz
LMV358 Power
2nd Order Low-Pass Butterworth filter 234 Hz
X50
X20

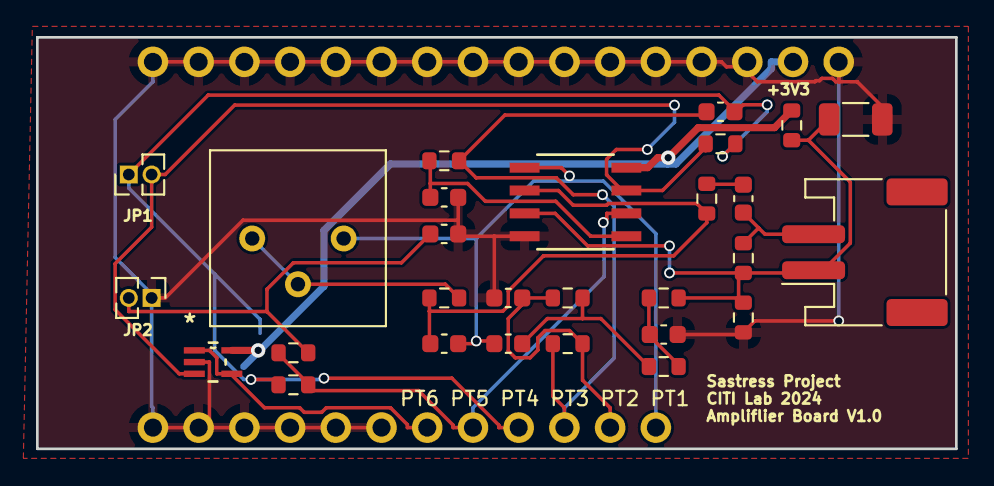
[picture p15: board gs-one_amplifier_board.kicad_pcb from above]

Board: 2 copper layers, 51.1 x 22.9 mm, 29 parts (0 on the bottom side), 18 nets.

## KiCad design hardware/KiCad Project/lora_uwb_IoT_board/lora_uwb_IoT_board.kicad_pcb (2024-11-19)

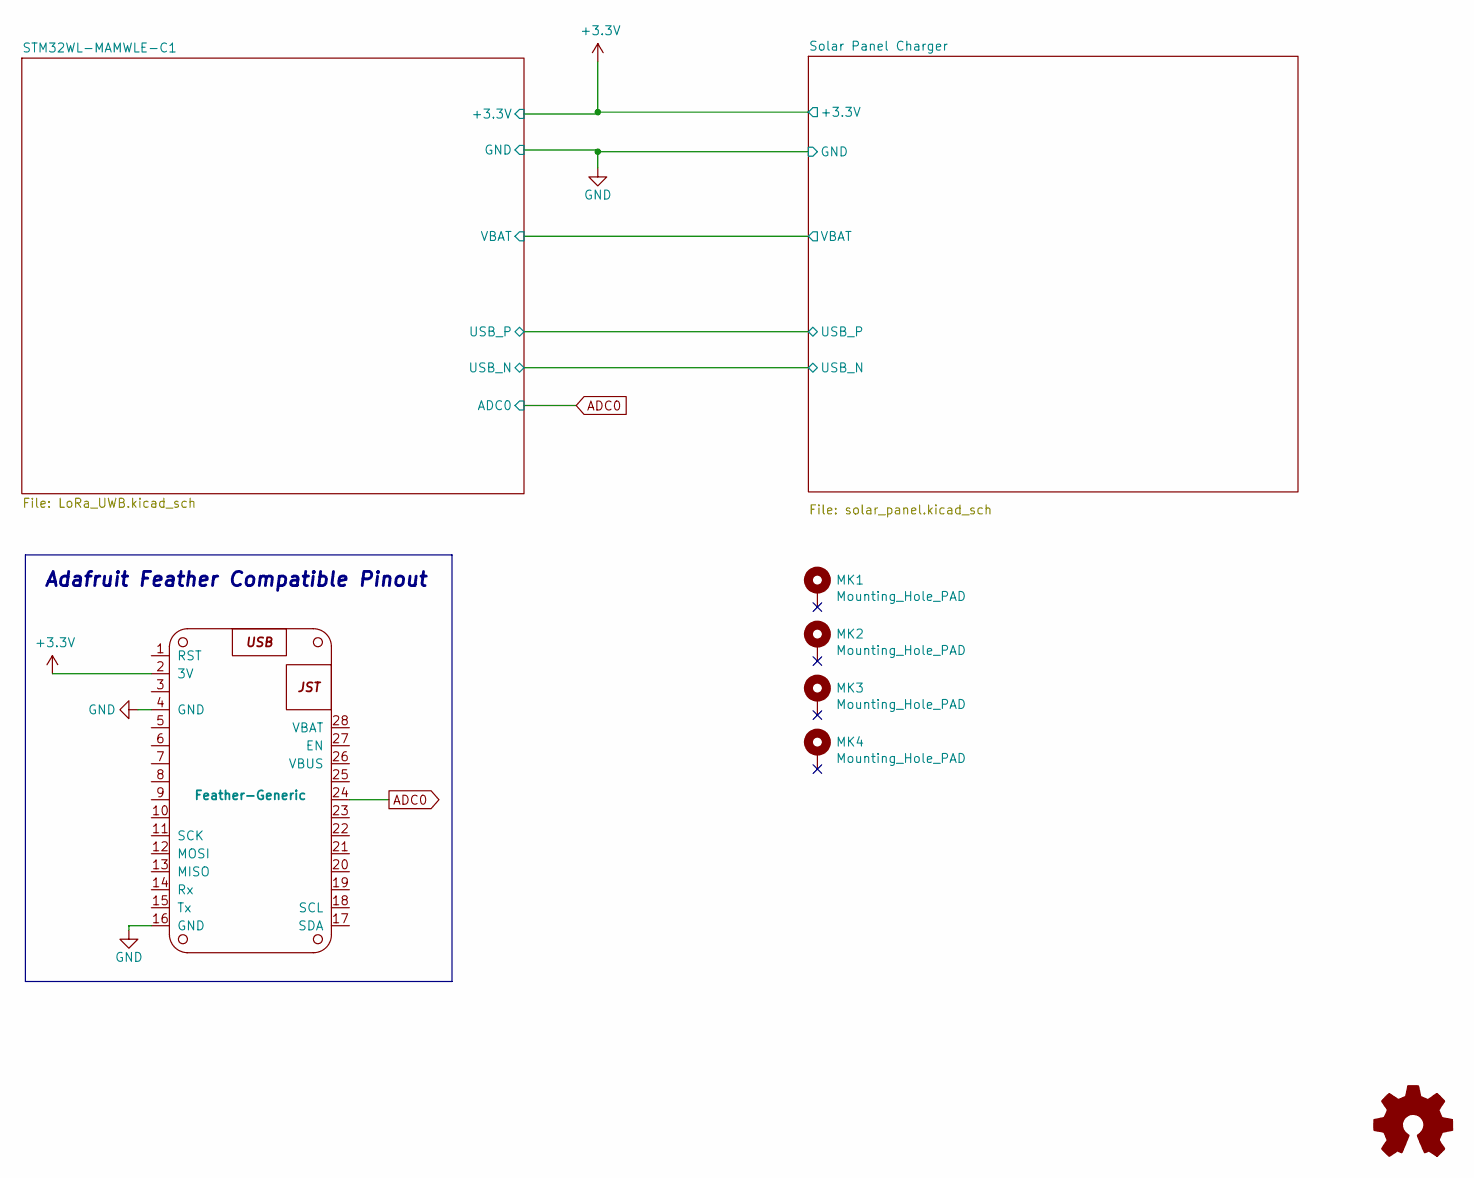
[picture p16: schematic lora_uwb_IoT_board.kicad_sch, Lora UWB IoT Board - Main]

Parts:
MK1, MK2, MK3, MK4: Mounting_Hole_PAD; MountingHole_2.7mm
U300: Feather-Generic; Feather-Generic-no-holes

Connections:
+3V3: U300.2 (3V); also elsewhere on the board
ADC0: U300.24; also elsewhere on the board
GND: U300.4 (GND), U300.16 (GND); also elsewhere on the board

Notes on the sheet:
Adafruit Feather Compatible Pinout

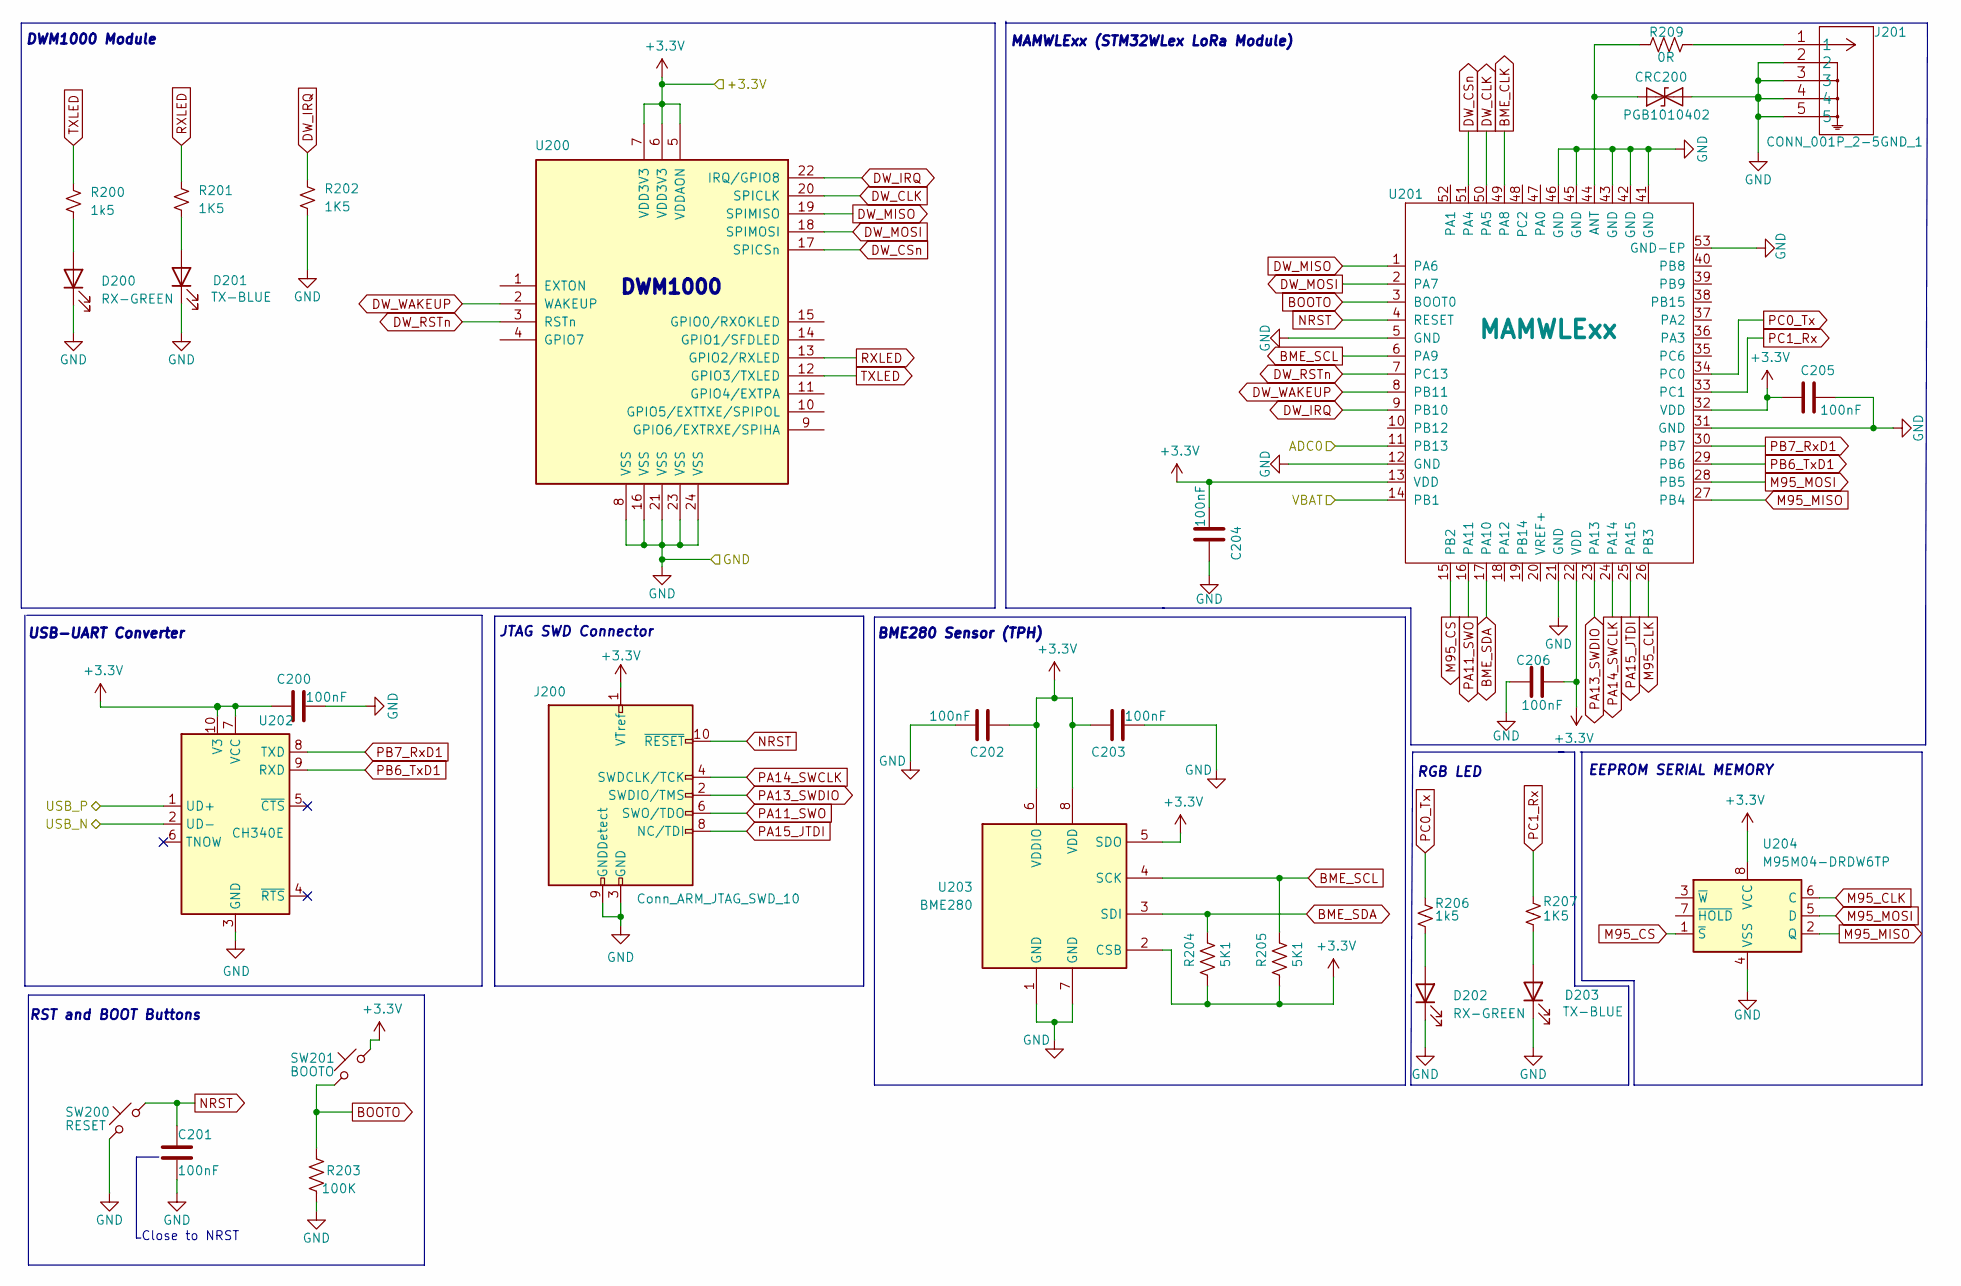
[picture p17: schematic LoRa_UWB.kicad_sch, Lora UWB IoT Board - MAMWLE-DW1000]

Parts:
C200, C201, C202, C203, C204, C205, C206: 100nF; C_0402_1005Metric; MPN GRM155R61A104KA01D
CRC200: PGB1010402; PGB1010402KR; MPN PGB1010402KR
D200, D202: RX-GREEN; LED_0603_1608Metric; MPN LTST-C191KGKT
D201, D203: TX-BLUE; LED_0603_1608Metric; MPN LTST-C191TBKT
J200: Conn_ARM_JTAG_SWD_10; PinHeader_2x05_P1.27mm_Vertical_SMD; MPN 20021121-00010C4LF
J201: CONN_001P_2-5GND_1; 142-0701-851; MPN 142-0701-851
R200, R206: 1k5; R_0402_1005Metric; MPN RC0402JR-071K5L
R201, R202, R207: 1K5; R_0402_1005Metric; MPN RC0402JR-071K5L
R203: 100K; R_0402_1005Metric; MPN RC0402JR-07100KL
R204, R205: 5K1; R_0402_1005Metric; MPN RC0402FR-075K1L
R209: 0R; R_0402_1005Metric; MPN RC0402JR-070RL
SW200: RESET; SW_Push_1P1T_NO_Vertical_Wuerth_434133025816; MPN 434133025816
SW201: BOOTO; SW_Push_1P1T_NO_Vertical_Wuerth_434133025816; MPN 434133025816
U200: DWM1000; MPN DWM1000
U201: MAMWLExx; MPN MAMWLE-02
U202: CH340E; MSOP-10_3x3mm_P0.5mm; MPN COM-16278
U203: BME280; Bosch_LGA-8_2.5x2.5mm_P0.65mm_ClockwisePinNumbering; MPN 828-1063-2-ND
U204: M95M04-DRDW6TP; TSSOP-8_4.4x3mm_P0.65mm

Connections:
+3V3: C200.1, C202.1, C203.1, C204.2, C205.2, C206.1, J200.1 (VTref), R204.2, R205.2, SW201.2, U200.5 (VDDAON), U200.6 (VDD3V3), U200.7 (VDD3V3), U201.13 (VDD), U201.22 (VDD), U201.32 (VDD), U202.7 (VCC), U202.10 (V3), U203.2 (CSB), U203.5 (SDO), U203.6 (VDDIO), U203.8 (VDD), U204.8 (VCC); also elsewhere on the board
/STM32WL-MAMWLE-C1/USB_N: U202.2 (UD-); also elsewhere on the board
/STM32WL-MAMWLE-C1/USB_P: U202.1 (UD+); also elsewhere on the board
ADC0: U201.11 (PB13); also elsewhere on the board
BME_CLK: U201.49 (PA8)
BME_SCL: R205.1, U201.6 (PA9), U203.4 (SCK)
BME_SDA: R204.1, U201.17 (PA10), U203.3 (SDI)
BOOTO: R203.1, SW201.1, U201.3 (BOOT0)
DW_CLK: U200.20 (SPICLK), U201.50 (PA5)
DW_CSn: U200.17 (SPICSn), U201.51 (PA4)
DW_IRQ: R202.1, U200.22 (IRQ/GPIO8), U201.9 (PB10)
DW_MISO: U200.19 (SPIMISO), U201.1 (PA6)
DW_MOSI: U200.18 (SPIMOSI), U201.2 (PA7)
DW_RSTn: U200.3 (RSTn), U201.7 (PC13)
DW_WAKEUP: U200.2 (WAKEUP), U201.8 (PB11)
GND: C200.2, C201.2, C202.2, C203.2, C204.1, C205.1, C206.2, CRC200.2 (A2), D200.1 (K), D201.1 (K), D202.1 (K), D203.1 (K), J200.3 (GND), J200.5 (GND), J200.9 (GNDDetect), J201.2, J201.3, J201.4, J201.5, R202.2, R203.2, SW200.1, U200.8 (VSS), U200.16 (VSS), U200.21 (VSS), U200.23 (VSS), U200.24 (VSS), U201.5 (GND), U201.12 (GND), U201.21 (GND), U201.31 (GND), U201.41 (GND), U201.42 (GND), U201.43 (GND), U201.45 (GND), U201.46 (GND), U201.53 (GND-EP), U201.54 (GND-EP), U201.55 (GND-EP), U201.56 (GND-EP), U201.57 (GND-EP), U201.58 (GND-EP), U201.59 (GND-EP), U201.60 (GND-EP), U201.61 (GND-EP), U201.62 (GND-EP), U201.63 (GND-EP), U201.64 (GND-EP), U201.65 (GND-EP), U201.66 (GND-EP), U202.3 (GND), U203.1 (GND), U203.7 (GND), U204.4 (VSS); also elsewhere on the board
M95_CLK: U201.26 (PB3), U204.6 (C)
M95_CS: U201.15 (PB2), U204.1 (~S)
M95_MISO: U201.27 (PB4), U204.2 (Q)
M95_MOSI: U201.28 (PB5), U204.5 (D)
NRST: C201.1, J200.10 (~RESET), SW200.2, U201.4 (RESET)
unnamed: CRC200.1 (A1), R209.1, U201.44 (ANT)
unnamed: D200.2 (A), R200.2
unnamed: D201.2 (A), R201.2
unnamed: D202.2 (A), R206.2
unnamed: D203.2 (A), R207.2
unnamed: J201.1, R209.2
PA11_SWO: J200.6 (SWO/TDO), U201.16 (PA11)
PA13_SWDIO: J200.2 (SWDIO/TMS), U201.23 (PA13)
PA14_SWCLK: J200.4 (SWDCLK/TCK), U201.24 (PA14)
PA15_JTDI: J200.8 (NC/TDI), U201.25 (PA15)
PB6_TxD1: U201.29 (PB6), U202.9 (RXD)
PB7_RxD1: U201.30 (PB7), U202.8 (TXD)
PC0_Tx: R206.1, U201.34 (PC0)
PC1_Rx: R207.1, U201.33 (PC1)
RXLED: R201.1, U200.13 (GPIO2/RXLED)
TXLED: R200.1, U200.12 (GPIO3/TXLED)
VBAT: U201.14 (PB1); also elsewhere on the board

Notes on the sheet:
DWM1000 Module
Close to NRST
DWM1000
RGB LED
JTAG SWD Connector
USB-UART Converter
BME280 Sensor (TPH)
MAMWLExx (STM32WLex LoRa Module)
RST and BOOT Buttons
EEPROM SERIAL MEMORY

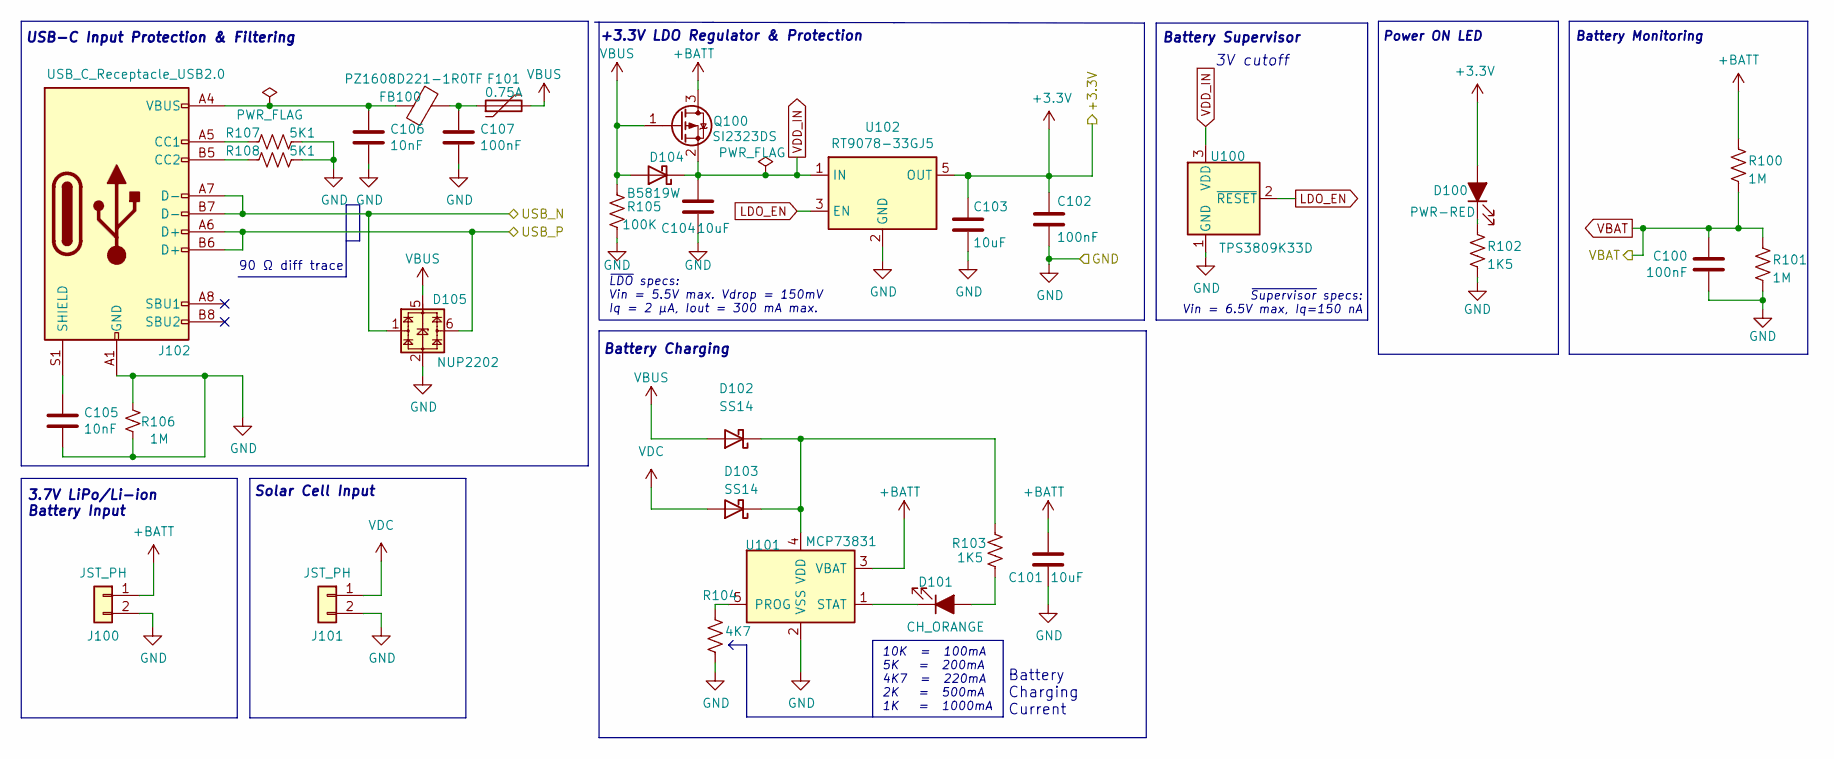
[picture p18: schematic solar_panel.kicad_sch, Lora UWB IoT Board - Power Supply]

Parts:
C100, C102, C107: 100nF; C_0402_1005Metric; MPN GRM155R61A104KA01D
C101, C103, C104: 10uF; C_0603_1608Metric; MPN GRT188C81A106ME13J
C105: 10nF; C_0402_1005Metric; MPN GRM155R61A103KA01D
C106: 10nF; C_0402_1005Metric; MPN GRM155R61A103KA01D; LCSC_Part# Murata Electronics
D100: PWR-RED; LED_0603_1608Metric; MPN LTST-C191KRKT
D101: CH_ORANGE; LED_0603_1608Metric; MPN LTST-C191KFKT
D102, D103: SS14; D_SMA; MPN SS14
D104: B5819W; D_SOD-123; MPN B5819W
D105: NUP2202; SOT-363_SC-70-6; MPN NUP2202W1T2G
F101: 0.75A; Fuse_0805_2012Metric; MPN SMD0805B075TF
FB100: PZ1608D221-1R0TF; L_0603_1608Metric; MPN HPZ1608D221-1R2TF
J100, J101: JST_PH; JST_PH_S2B-PH-SM4-TB_1x02-1MP_P2.00mm_Horizontal; MPN S2B-PH-SM4-TB(LF)(SN)
J102: USB_C_Receptacle_USB2.0; USB_C_Receptacle_Amphenol_12401548E4-2A; MPN 12401598E4#2A
Q100: SI2323DS; SOT-23; MPN SI2323DS-T1-GE3
R100, R101, R106: 1M; R_0402_1005Metric; MPN RC0402JR-071ML
R102, R103: 1K5; R_0402_1005Metric; MPN RC0402JR-071K5L
R104: 4K7; R_0402_1005Metric; MPN RC0402JR-074K7L
R105: 100K; R_0402_1005Metric; MPN RC0402JR-07100KL
R107, R108: 5K1; R_0402_1005Metric; MPN RC0402FR-075K1L
U100: TPS3809K33D; SOT-23; MPN TPS3809K33DBVRG4
U101: MCP73831; SOT-23-5; MPN MCP73831T-2ACI/OT
U102: RT9078-33GJ5; TSOT-23-5; MPN RT9078-33GJ5

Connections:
+3V3: C102.1, C103.1, D100.2 (A), U102.5 (OUT); also elsewhere on the board
+BATT: C101.1, J100.1, Q100.3 (D), R100.1, U101.3 (VBAT)
/STM32WL-MAMWLE-C1/USB_N: D105.1, J102.A7 (D-), J102.B7 (D-); also elsewhere on the board
/STM32WL-MAMWLE-C1/USB_P: D105.6, J102.A6 (D+), J102.B6 (D+); also elsewhere on the board
GND: C100.1, C101.2, C102.2, C103.2, C104.2, C105.1, C106.2, C107.2, D105.2, J100.2, J101.2, J102.A1 (GND), J102.A12 (GND), J102.B1 (GND), J102.B12 (GND), R101.2, R102.2, R104.2, R105.2, R106.1, R106.2, R107.1, R108.1, U100.1 (GND), U101.2 (VSS), U102.2 (GND); also elsewhere on the board
LDO_EN: U100.2 (~RESET), U102.3 (EN)
unnamed: C105.2, J102.S1 (SHIELD)
unnamed: C106.1, FB100.1, J102.A4 (VBUS), J102.A9 (VBUS), J102.B4 (VBUS), J102.B9 (VBUS)
unnamed: C107.1, F101.1, FB100.2
unnamed: D100.1 (K), R102.1
unnamed: D101.1 (K), U101.1 (STAT)
unnamed: D101.2 (A), R103.2
unnamed: D102.1 (K), D103.1 (K), R103.1, U101.4 (VDD)
unnamed: J102.A5 (CC1), R107.2
unnamed: J102.B5 (CC2), R108.2
unnamed: R104.1, U101.5 (PROG)
VBAT: C100.2, R100.2, R101.1; also elsewhere on the board
VBUS: D102.2 (A), D104.2 (A), D105.5, F101.2, Q100.1 (G), R105.1
VDC: D103.2 (A), J101.1
VDD_IN: C104.1, D104.1 (K), Q100.2 (S), U100.3 (VDD), U102.1 (IN)

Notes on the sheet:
3V cutoff
Solar Cell Input
90 Ω diff trace
+3.3V LDO Regulator & Protection
Battery Charging Current
10K = 100mA 5K = 200mA 4K7 = 220mA 2K = 500mA 1K = 1000mA
3.7V LiPo/Li-ion Battery Input
Battery Supervisor
Power ON LED
Battery Monitoring
~{Supervisor} specs: Vin = 6.5V max, Iq=150 nA
USB-C Input Protection & Filtering
~{LDO} specs: Vin = 5.5V max. Vdrop = 150mV Iq = 2 μA, Iout = 300 mA max.
Battery Charging

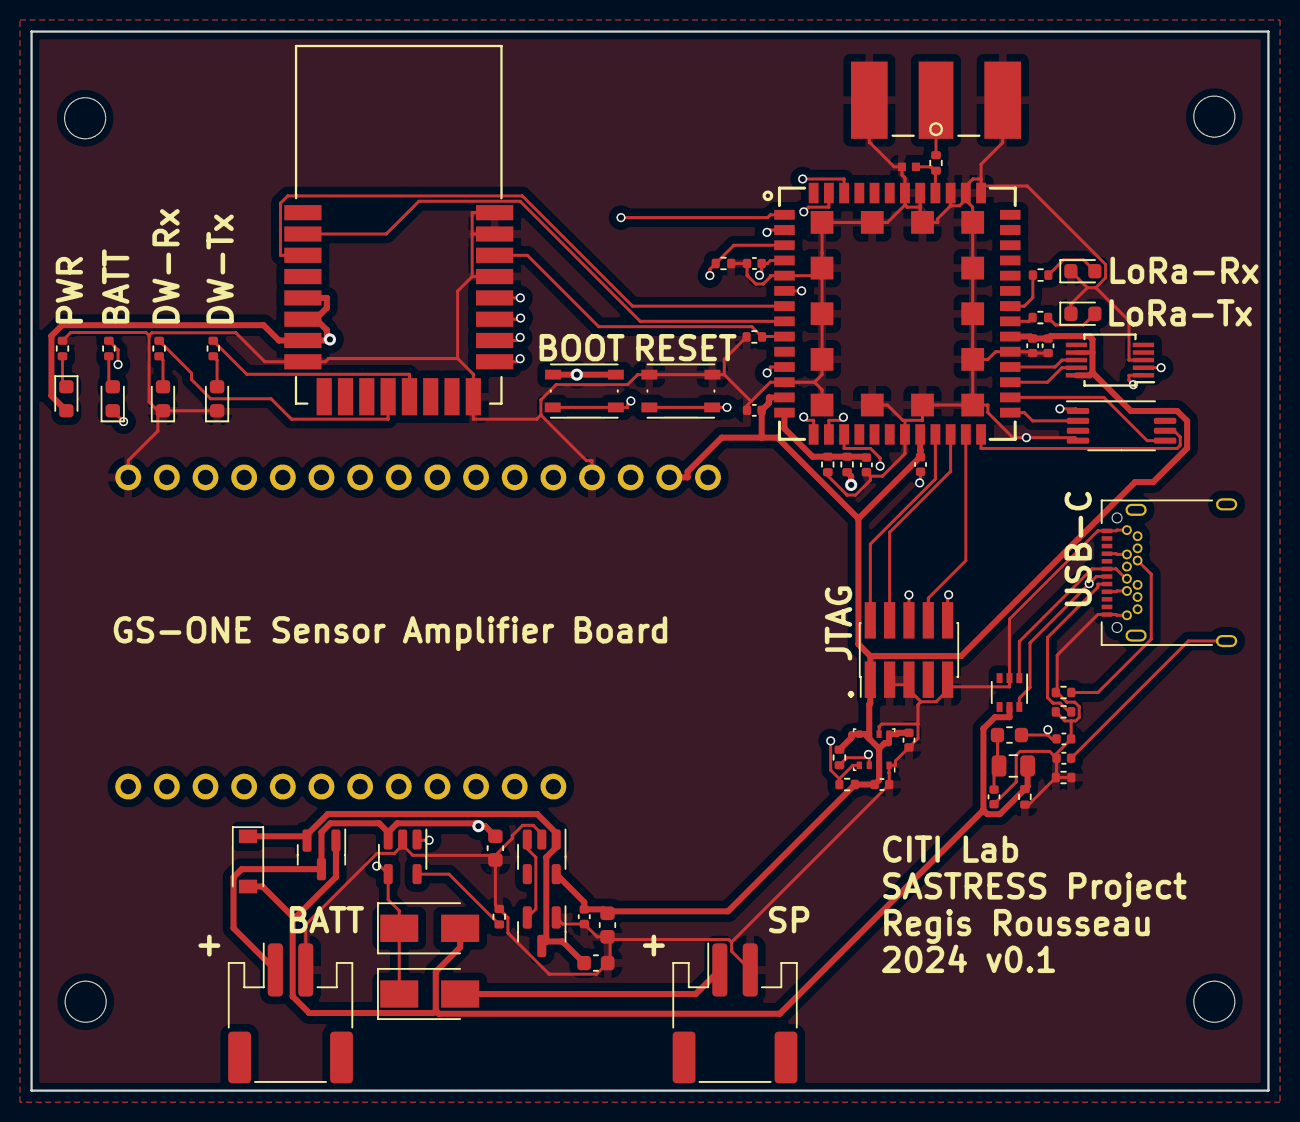
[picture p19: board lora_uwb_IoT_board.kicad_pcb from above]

Board: 4 copper layers, 81.3 x 69.6 mm, 67 parts (0 on the bottom side), 52 nets.

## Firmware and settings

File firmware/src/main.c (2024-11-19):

#include <zephyr/device.h>
#include <zephyr/kernel.h>
#include "app_lorawan.h"
#include "app_flash.h"

//  ======== globals ============================================
uint16_t cnt;           // declaration of counter index

//  ======== interrupt sub-routine ===============================
void adc_work_handler(struct k_work *work_geo)
{
	const struct device *dev;
	app_rom_handler(dev);
	cnt++;
}
K_WORK_DEFINE(geo_work, adc_work_handler);

void adc_timer_handler(struct k_timer *timer)
{
	k_work_submit(&geo_work);
}
K_TIMER_DEFINE(adc_timer, adc_timer_handler, NULL);

//  ======== main ===============================================
int8_t main(void)
{
	const struct device *dev;
	struct nvs_fs fs;
	uint16_t vbat;
	cnt = 0;
	uint32_t max_cnt = 0;
	int8_t ret;
	
	// initialization of all devices
	app_bme280_init(dev);
	app_stm32_vbat_init(dev);
	app_rom_init(dev);
	app_flash_init(&fs);

	// initialization of LoRaWAN
	app_lorawan_init(dev);

	printk("Geophone Measurement and Process Information\nBoard: %s\n", CONFIG_BOARD);
	
	// beginning of isr timer
	k_timer_start(&adc_timer, K_NO_WAIT, K_MSEC(5));

	while (1) {
		// counter value for waiting 30 min -> 1 800 000ms
		if (cnt >= 1800000) {
			app_flash_handler(&fs);
		}
	}
	return 0;
}

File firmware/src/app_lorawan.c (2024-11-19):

/*
 * Copyright (c) 2023
 * Regis Rousseau
 * Univ Lyon, INSA Lyon, Inria, CITI, EA3720
 * SPDX-License-Identifier: Apache-2.0
 */

 #include "app_lorawan.h"
 #include "app_flash.h"

//  ======== globals ============================================
// downlink callback
static void dl_callback(uint8_t port, bool data_pending, int16_t rssi, int8_t snr, uint8_t len, const uint8_t *data)
{
	printk("downlink data received: ");
    for(int8_t i=0; i < len; i++) {
		printk("%02X ", data[i]);
	}
    printk("\n");
	printk("port: %d, pending: %d, RSSI: %ddB, SNR: %dBm\n", port, data_pending, rssi, snr);
}

// adr change callback
static void lorwan_datarate_changed(enum lorawan_datarate dr)
{
	uint8_t unused, max_size;

	lorawan_get_payload_sizes(&unused, &max_size);
	printk("new datarate: DR_%d, max payload: %d\n", dr, max_size);
}

static const struct gpio_dt_spec led_tx = GPIO_DT_SPEC_GET(LED_TX, gpios);
static const struct gpio_dt_spec led_rx = GPIO_DT_SPEC_GET(LED_RX, gpios);

//  ======== app_loarwan_init ===================================
int8_t app_lorawan_init(const struct device *dev)
{
    struct lorawan_join_config join_cfg;
	static struct nvs_fs fs;
	uint16_t dev_nonce = 0u;

    int8_t ret;
	int8_t itr = 1;
	ssize_t err;
	uint8_t dev_eui[] 	= LORAWAN_DEV_EUI;
	uint8_t join_eui[]	= LORAWAN_JOIN_EUI;
	uint8_t app_key[]	= LORAWAN_APP_KEY;

    // setup tx led at GPIO PC0
    ret = gpio_pin_configure_dt(&led_tx, GPIO_OUTPUT_ACTIVE);
	if (ret < 0) {
		return 0;
	}
	// setup rx led at GPIO PC1
    ret = gpio_pin_configure_dt(&led_rx, GPIO_OUTPUT_ACTIVE);
	if (ret < 0) {
		return 0;
	}

	// initialization and reading/writing the devnonce parameter
	app_flash_init(&fs);
	app_flash_init_param(&fs, NVS_DEVNONCE_ID, &dev_nonce);

	 printk("starting lorawan node\n");
    // getting lora sx1276 device
	dev = DEVICE_DT_GET(DT_ALIAS(lora0));
	if (!device_is_ready(dev)) {
		printk("%s: device not ready\n", dev->name);
		return 0;
	}

	printk("starting lorawan stack\n");
    // starting device
	ret = lorawan_set_region(LORAWAN_REGION_EU868);
	ret = lorawan_start();
	if (ret < 0) {
		printk("lorawan_start failed. error: %d\n", ret);
		return 0;
	}

     // enable adr
    lorawan_enable_adr(true);

	// enable callbacks
	struct lorawan_downlink_cb downlink_cb = {
		.port = LW_RECV_PORT_ANY,
		.cb = dl_callback
	};
	lorawan_register_downlink_callback(&downlink_cb);
	lorawan_register_dr_changed_callback(lorwan_datarate_changed);  

	// configuration of lorawan parameters 
    join_cfg.mode = LORAWAN_ACT_OTAA;
	join_cfg.dev_eui = dev_eui;
	join_cfg.otaa.join_eui = join_eui;
	join_cfg.otaa.app_key = app_key;
	join_cfg.otaa.nwk_key = app_key;
	join_cfg.otaa.dev_nonce = dev_nonce;

	do {
		printk("joining network using OTAA, dev nonce %d, attempt %d\n", join_cfg.otaa.dev_nonce, itr++);
		ret = lorawan_join(&join_cfg);

		// flashing of the LED when a packet is received
		ret = gpio_pin_toggle_dt(&led_rx);
			if (ret < 0) {
				return 0;
			}

		if (ret < 0) {
			if ((ret =-ETIMEDOUT)) {
				printk("timed-out waiting for response.\n");
			} else {
				printk("join network failed. error: %d\n", ret);
			}
		} else {
			printk("OTAA join successful\n");
		}

		dev_nonce++;
		join_cfg.otaa.dev_nonce = dev_nonce;

		// save value away in Non-Volatile Storage.
		err = nvs_write(&fs, NVS_DEVNONCE_ID, &dev_nonce, sizeof(dev_nonce));
		if (err < 0) {
			printk("NVS: failed to write id %d. error: %d\n", NVS_DEVNONCE_ID, err);
		}

		if (ret < 0) {
			// if failed, wait before re-trying.
			k_sleep(DELAY);
		}
	} while (ret != 0);
    return 0;
}

//  ======== app_loarwan_get_time ===============================
time_t app_lorawan_get_time(const struct device *dev)
{
    int8_t ret;
    uint32_t gps_time;
	time_t unix_time;
	struct tm timeinfo;
	char buf[32];

    // getting lora sx1276 device
    dev = DEVICE_DT_GET(DT_ALIAS(lora0));
	if (!device_is_ready(dev)) {
		printk("%s: device not ready\n", dev->name);
		return 0;
	}
	
    // getting timstamp from lorawan
    lorawan_clock_sync_run();
    ret = lorawan_clock_sync_get(&gps_time);
	if (ret != 0) { 
			printk("lorawan_clock_sync_get failed. error: %d\n", ret);
		} else {
			/* 
			 * The difference in time between UNIX (epoch Jan 1st 1970) and
			 * GPS (epoch Jan 6th 1980) is 315964800 seconds. This is a bit
			 * of a fudge as it doesn't take into account leap seconds and 
			 * hence is out by roughly 18 seconds. 
			 *
			 */
			unix_time = gps_time - 315964800;
			localtime_r(&unix_time, &timeinfo);
			strftime(buf, sizeof(buf), "%A %B %d %Y %I:%M:%S %p %Z", &timeinfo);
			printk("GPS Time: %lu, UTC Time: %s", gps_time, buf);
		}
    return unix_time;
}

//  ======== app_loarwan_handler ================================
int8_t app_lorawan_handler(const struct device *dev, uint16_t *data_tx)
{   
    int8_t ret;

    dev = DEVICE_DT_GET(DT_ALIAS(lora0));

    // transmission of packets on lorawan protocole
	printk("sending data...\n");
	ret = lorawan_send(2, data_tx, sizeof(data_tx), LORAWAN_MSG_CONFIRMED);
	if (ret == -EAGAIN) {
			printk("lorawan_send failed: %d. continuing...\n", ret);
			k_sleep(DELAY);
			return 0;
	} else if (ret < 0) {
		printk("lorawan_send failed: %d. continuing...\n", ret);
		k_sleep(DELAY);
		return 0;;
	}

    // flashing of the LED when a packet is transmitted
	ret = gpio_pin_toggle_dt(&led_tx);
	if (ret < 0) {
		return 0;
	}
	printk("data sent !\n");
	//k_sleep(DELAY);
	return 0;
}
